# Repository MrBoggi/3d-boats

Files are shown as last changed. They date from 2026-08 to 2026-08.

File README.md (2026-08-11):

# 3dBoats

A collection of parametric OpenSCAD boat projects intended for 3D printing.

## Repository layout

```text
3dBoats/
├── projects/   # Individual printable boat projects
├── shared/     # Reusable OpenSCAD modules and component wrappers
└── scripts/    # Repository-wide build helpers (when added)
```

Each directory under `projects/` contains its own source files, build script,
and project-specific documentation.

## Projects

- [`projects/01-21ft-rib`](projects/01-21ft-rib/) — 1:10 scale, 660 mm RC RIB
  with a three-part V-hull, removable interior, and steerable outboard motor.

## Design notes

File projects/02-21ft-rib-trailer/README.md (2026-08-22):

# Båthenger for 21 ft RIB — designplan

Parametrisk boggihenger i skala 1:10, utviklet for båten i
[`../01-21ft-rib`](../01-21ft-rib/README.md). Hengeren skal kunne vises sammen
med båten, skrives ut på Bambu Lab A1 og bygges som en funksjonell RC-modell
med roterende hjul, vippbar boggi og justerbare skrogstøtter.

## Status

Detaljert digital review-versjon er implementert. Den inneholder komplett
sammenstilling, direkte skrogreferanse fra prosjekt 01 og 35 separate
eksportmål. En forstørret todelt V-front, rammeskjøter, tverrbjelkefester,
boggi-endestopp, M4-hjulaksler, synlige M4-muttere og separate 12 mm sekskantadaptere med avstandshylse,
justerbare støtter og en fremoverlent, avstivet vinsjstolpe med V-stopp på båtsiden er modellert. Modellen er kontrollert
med OpenSCAD, men ikke fysisk printet eller verifisert.

## Kjøpt RC-kobling

[AliExpress-produkt 1005005631960547](https://www.aliexpress.com/item/1005005631960547.html) er et AJRC justerbart `drop hitch receiver` for bilsiden på 1:10-crawlere som TRX-4 og SCX10. På hengeren trengs den matchende metallkloen, ikke en kopi av bilfestet.

CAD-en bruker den vanligste dokumenterte 1:10-standarden:

- 5,8–6,0 mm kule på trekkbilen;
- trailerklør for 6 mm kule;
- omtrent 35 mm lang metallklo;
- M3-gjenget sokkel i bakkant av kloen;
- 9 mm M3-stud ut fra hengeradapteren.

Et dokumentert eksempel er [Absima 2320126](https://rcmodelshopdirect.com/shop/accessories/rc-crawler-accessories/absima-1-10th-trailer-hitch-2320126/), som oppgir 35 mm lengde, M3-sokkel og 6 mm kule. Kompatible 6 mm kulefester finnes også fra [Integy](https://integy.shop/products/rock-crawlers-hop-up-parts-c33970). Produktet og AliExpress-variantene er `example`, ikke fysisk testet. Kontroller at valgt bilfeste leveres med 5,8–6 mm kule, og kjøp en trailerklør med M3-sokkel hvis den ikke følger med.

Hengeren har en separat printet frontadapter. Den overlapper senterbjelken 18 mm og festes med to vertikale M3-bolter. En fanget aksial M3-skrue gir 9 mm gjengestud til metallkloen. Adapteren kan dermed endres senere uten å printe V-draget på nytt.

## Visuelle referanser

Utformingen følger vanlige radius-toppskjermer for tandemakslede båthengere,
brede rektangulære LED-baklys og Y-/V-formede baugstopp på vinsjstolpen:

- [Tandemskjermer – BoatTrailerParts](https://www.boattrailerparts.com/Tandem-Axle-Boat-Trailer-Fenders_c_85.html)
- [Skrå vinsjstolpe med avstiving – BoatTrailerParts](https://www.boattrailerparts.com/Boat-Trailer-Winch-Post-Angled-3-inch-x-3-inch-x-24-inch-Tall-Galvanized_p_1960.html)
- [45° justerbar vinsjstolpe – etrailer](https://www.etrailer.com/search/Bow%2Bstop%2Bpost)
- [Plassering av baugstopp – etrailer](https://www.etrailer.com/faq-4-choices-buying-a-boat-trailer.aspx)
- [Rektangulære båthengerlys – EZ Loader](https://ezloadertrailers.com/products/ez-loader-updated-taillight-set-7-5-x-3-5-411-3002)

Referansene angir form og plassering; komponentene i CAD er egne skalerte
printdeler og er ikke fysisk testet.

## Grunnlag fra prosjekt 01

| Egenskap | Verdi |
|---|---:|
| Skala | 1:10 |
| Båtlengde | 660 mm |
| Maksimal båtbredde | 252 mm |
| Skrogtype | V-bunn, 26° referanse-deadrise, integrerte pongtonger |
| Båtens koordinater | X baug→hekk, Y babord→styrbord, Z kjøl→opp |
| Målskriver | Bambu Lab A1, 256 × 256 × 256 mm |

Hengermodellen skal importere eller gjengi skrogets kontaktprofil fra prosjekt
01. Parallelle, manuelt kopierte skrogmål skal unngås.

## Foreslått hovedkonsept

- Sveiset stålramme gjengitt som en modulær, printet kanal-/boksramme.
- A-ramme i front med kulekobling, langsgående 12 × 18 mm senterbjelke og fremoverlent vinsjtårn med doble skråstag på framsiden.
- V-baugstoppen står på båtsiden av vinsjtrommelen, slik at skroget stoppes før det kan nå trommel eller sveiv.
- To langsgående hovedvanger med tverrbjelker og separate skjøtestykker.
- Tandemakslet boggi på hver side. Hver boggi vipper rundt ett sentralt lagerpunkt,
  slik at begge hjul kan følge underlaget.
- Fire kjølruller langs senterlinjen tar hovedvekten.
- To par justerbare dobbeltrullestøtter støtter V-bunnen uten å belaste pongtongene.
- Motorens senterlinje holdes åpen bak X = 585 mm; forstørrede baklys og skilt sitter på bjelken foran.
- Én lang, buet tandemskjerm per side dekker begge hjul og festes med separate M3-braketter.
- En utskiftbar V-formet baugstopp i TPU sitter over vinsjtrommelen og tar imot V-baugen uten å bære skrogvekten.
- Baugstøtte og vinsjtrommel låser båten i lengderetningen. En egen akterstropp
  reserveres i modellen.

## Foreløpig dimensjoneringskonvolutt

| Parameter | Startverdi | Begrunnelse |
|---|---:|---|
| Total lengde | 800 mm | 660 mm båt, drag og klaring ved hekk |
| Ramme fra baugstøtte til akterende | 700 mm | Full understøttelse av skroget |
| Ytre rammebredde | 220 mm | Under båtens 252 mm maks. bredde |
| Sporvidde, hjulsenter | 290 mm | Klaring utenfor pongtongene |
| Maksimal totalbredde | 317 mm | Foreløpig hjul-/skjermkonvolutt |
| Hjuldiameter / reservert bredde | 65 / 27 mm | AliExpress-hjul; bredde må kontrollmåles |
| Hjulaksel | M4 × 55 mm | Ø4,3 mm klaringshull og fanget skruehode |
| Akselavstand i boggi | 78 mm | Klaring mellom 65 mm hjul |
| Bakkeklaring under ramme | 22 mm | Funksjonell modell på jevnt underlag |
| Klaring mellom skrog og hard støtte | 1.0 mm | Plass til myke støtteflater |
| Boggiens vinkelutslag | ±12° | Terrengbevegelse uten kontakt med ramme |

Valgt eksempel er [AliExpress-produkt 1005009693636383](https://www.aliexpress.com/item/1005009693636383.html), oppgitt som ARRMA
ARA550116-kompatibelt hjul med diameter 65 mm og 12 mm sekskantfeste. CAD-en
reserverer 27 mm hjulbredde inntil et fysisk hjul kan måles. Hvert hjul monteres med en separat printet sekskantadapter med integrert
avstandshylse, M4 × 55 mm skrue, to skiver og M4 låsemutter. Skrue, skiver
og mutter vises nå også i normal `assembly`, mens klaringsvolumene fortsatt
styres av `show_hardware`. Adapteren er 11,5 mm over flatene for 0,25 mm klaring per side.
Produktet er foreløpig et eksempel, ikke fysisk testet. ARRMA oppgir 12 mm
sekskantfeste for ARA550116, og det tilhørende GROM-akselsettet ARA311231
bruker M4-hjulmuttere: [hjuldata](https://www.arrma-rc.com/en/product/arrma-dboots-fortress-tire-set-glued-red-2-pairs/ARA550116.html) og
[akseldata](https://www.arrma-rc.com/de/product/arrma-metal-axle-and-wheel-hex-set-b-4-grom/ARA311231.html).

Alle startverdier skal ligge i `scad/config.scad` og kunne justeres etter første
digital prøvepass. Totalbredden er større enn byggeplaten, så aksler,
boggiarmer og hjul må være separate deler.

## Designfaser

### 1. Lås båtens plassering og kontaktpunkter

Plasser båten med samme X/Y/Z-retning som i prosjekt 01. Definer et eget
`boat_reference`-oppsett med:

- kjølens høyde langs X;
- V-bunnens høyde ved valgte støttebredder;
- maksimal pongtongkonvolutt;
- motorens og akterspeilets frie område;
- båtens tyngdepunkt som en justerbar antakelse frem til det måles fysisk.

Første mål er minst 5 mm fri avstand mellom hard hengerramme og skrog/pongtong
ved nominell plassering.

### 2. Lag en enkel layoutmodell

Modeller først bare klaringsvolumer for båt, hjul, aksler, kobling og
vinsjtårn. Kontroller ovenfra og fra siden at:

- båten er sentrert og ikke treffer skjermer eller vinsjtårn;
- akterspeil og påhengsmotor har fri passasje gjennom den åpne akterenden;
- estimert tyngdepunkt ligger litt foran boggisenteret;
- kulekoblingen får tilstrekkelig sving- og høydeklaring.

### 3. Dimensjoner ramme og utskriftsdeling

De parallelle hovedvangene starter ved X = 276 mm, direkte mot bakkanten av tverrbjelken ved X = 270 mm, og deles ved X = 440 mm.
Fronten er en stor V fra koblingen ved X = -108 mm til vangene ved X = 270 mm.
V-en deles ved X = 60 mm med 10 mm overlapp og gjennomgående M3-skruer. Tverrbjelkene skal være separate slik at samlet bredde ikke bestemmer
utskriftsretningen. Legg mest materiale rundt boggifeste, vinsjtårn og skjøter.

### 4. Utvikle boggien som egen mekanisme

Hver side får én vippende boggiarm med to separate hjulaksler. Reserver først
hardware-konvolutter for M4 × 55 mm hjulskruer, skiver, låsemuttere og
separate 12 mm sekskantadaptere. Boggiens senterbolt skal være tilgjengelig uten å demontere rammen.
Mekaniske endestopp begrenser vinkelutslaget og hindrer at dekk treffer rammen.

### 5. Tilpass kjølruller og sidestøtter

Plasser kjølruller ved omtrent X = 110, 270, 430 og 591,3 mm i båtens koordinater,
og finjuster dem mot den faktiske kjølkurven. Sidestøttene plasseres parvis nær
de to midtre/akterste sonene, med vinkel bestemt av skrogets lokale V-flate.
Støttehodene skal være utskiftbare og ha flater for TPU-, filt- eller
gummibelegg. Pongtongene skal ikke være lastbærende.

### 6. Legg til opptrekk og sikring

Vinsjtårnet heller omtrent 29° fremover fra vertikalen. Den brede fotplaten er erstattet av en 12 × 18 mm senterbjelke fra V-spissen til tverrbjelken ved X = 34 mm. Stolpefoten står direkte på dette krysningspunktet med gjennomgående M3-feste, mens to diagonaler lander på senterbjelken foran. Baugstoppen er en separat, kompakt TPU-V mellom to faste gaffelører på båtsiden av trommelen. En gjennomgående M3-pivot med 0,4 mm sideklaring, skiver og låsemutter lar hele V-klossen selvjustere opptil ±15° i lengderetningen,
og vinsjen får gjennomgående aksel og håndsveiv. Modellen reserverer føring for
line, sikkerhetskjetting og stroppepunkter ved akterenden. Dette modelleres etter
at båtens hvilestilling er låst.

### 7. Verifiser og iterer

Lag først små prøveutskrifter av rammeskjøt, boggilager, hjuladapter og én
skrogstøtte. Deretter:

1. Render alle deler enkeltvis og som komplett henger.
2. Render en debug-sammenstilling med båt og alle hardware-konvolutter.
3. Kontroller manifold geometri og byggevolum for hver eksport.
4. Print én boggi og test vipping, hjulfrigang og skrueadkomst.
5. Print en kort rammeseksjon med støtte og fysisk prøv mot skroget.
6. Monter full ramme, juster støttehøyder og mål faktisk kuletrykk.
7. Lås parametere først etter rulle-, sving- og lastetest med den ferdige båten.

## Filstruktur

```text
02-21ft-rib-trailer/
├── README.md
├── build.sh
├── scad/
│   ├── config.scad
│   ├── hardware.scad
│   ├── boat_reference.scad
│   ├── frame.scad
│   ├── bogie.scad
│   ├── fenders.scad
│   ├── coupler.scad
│   ├── supports.scad
│   ├── winch.scad
│   └── assembly.scad
├── stl/
├── 3mf/
└── png/
```

`assembly.scad` har en `selected_part`-velger for hver printdel. Variablene
`show_boat`, `show_outboard`, `show_road` og `show_hardware` styrer henholdsvis
skrogreferansen, den komplette motorreferansen, veireferansen ved Z = 0 og
hardware-konvoluttene. `show_keel_contact_debug=true` legger fire
ugjennomsiktige turkise skrogsnitt over kjølrullene, slik at anlegget kan
vurderes uten transparent-overlapping.
Motoren gjenbrukes fra båtprosjektets originalmodell med original kort stamme
og motorfeste. XL-avstandsstykket er ikke med i trailervisningen. Motoren vises
uten tilt, slik at akter- og propellklaringen kan vurderes mot veien.

## Bygg og forhåndsvisning

Åpne hele sammenstillingen med båten:

```sh
openscad scad/assembly.scad
```

Eksporter én del, for eksempel boggiarmen:

```sh
openscad -o bogie_arm.stl \
  -D 'selected_part="bogie_arm"' \
  -D 'show_boat=false' \
  scad/assembly.scad
```

Etter visuell godkjenning eksporteres hele settet og tre PNG-visninger med:

```sh
./build.sh --approved
```

## Implementerte printmål

- Ett 164 mm midtsegment og ett 145 mm aktersegment per hovedvange; vangene slutter ved X = 585 mm.
- To utvendige skjøtelasker, én på yttersiden av hver vange ved X = 440 mm. Innvendige lasker er fjernet fordi de kolliderte med midtbjelkens festeområde.
- Én fullbredde frontbjelke ved X = 270 mm, én egen forkortet midtbjelke ved X = 430 mm og én tilpasset lysbjelke ved X = 591,3 mm. Den tidligere tverrbjelken i vangskjøten ved X = 440 mm er fjernet, slik at skjøteboltene ikke ligger i en delesøm.
- Midtbjelken har 0,3 mm sideklaring til vangene; lysbjelken har 0,3 mm endeklaring bak vangene. Hver skjøt bruker egne 3 mm over-/underplater på begge sider, totalt fire plater per bjelke.
- V-bakdelen stopper plant ved forkanten av tverrbjelken ved X = 270 mm, og hovedvangene starter ved bakkanten. Fire identiske 3 mm skjøteplater, én over og én under på hver side, forbinder V-arm, tverrbjelke og hovedvange med tre M3-bolter per side.
- Todelt, forstørret V-front med en reell halv-i-halv-skjøt, 0,3 mm vertikal printklaring og to M3-bolter per arm, integrerte broer og langsgående senterbjelke frem til vinsjtverrbjelken.
- Separat frontadapter med 18 mm halv-i-halv-tunge, 0,3 mm vertikal klaring, to M3-rammebolter og aksial M3-stud for kjøpt 6 mm trailerklør.
- To boggiarmer og to åpne clevisfester med 4 mm inner-/ytterører, 1,2 mm lagergap, 0,8 mm skiver og fanget M3-mutter. Hvert feste har toppflens og to vertikale M3-bolter gjennom hovedvangen; endestoppene gir verifisert ±12° utslag.
- Fire separate PETG/ASA-sekskantadaptere for kjøpehjul med 12 mm feste og integrert Ø10 mm avstandshylse.
- Alle bærende rammebjelker har 12 × 18 mm profil, slik at V-front, hovedvanger og tverrbjelker møtes med plane over- og undersider uten påbygde kiler.
- Fire kjølruller og åtte separate, speilbare sidebraketter som står på oversiden av V-broen eller tverrbjelken og festes i samsvarende M3-hull. Rullene har en konkav 26° V-profil, Ø7 mm i senter og Ø23 mm ved endene. Holderne består av to speilbare, separate sidebraketter per rull, er åpne under rullens rotasjonsbane og har sideføtter, 1 mm aksial endeklaring og minst 0,4 mm radial klaring over bjelken. Båtens referansehøyde er løftet 6 mm for å gi plass til den reelle V-rullekonvolutten. Akselhøydene er avledet fra skrogets målte kjølhøyde ved hver stasjon og gir minst 0,3 mm digital klaring til den analytiske V-bunnen.
- Fire støttehylser med bolteflens mot tverrbjelkene, fire justerbare poster, fire bolteforbundne rulleåk og åtte separate sideruller. Hver siderulle sitter i en separat wobble-holder med M3-sekundærpivot rundt X-aksen, ±10° mekanisk utslag og fysiske endestopp. Hovedåket har Y-pivot mot støtteposten og skrogavledet lengdevipp på ca. -3,0° foran og -0,04° bak. Siderullene har en svakt konveks TPU-profil, Ø16 mm i midten og Ø13 mm ved endene, for å redusere kantkontakt.
- Fremoverlent vinsjstolpe uten bred fotplate; stolpefoten treffer vinsjtverrbjelken direkte, og doble frontstag treffer senterbjelken med hvert sitt M3-feste. Trommel, sveiv og boltet V-baugstopp på båtsiden er separate deler.
- To forstørrede lyktehus ved Y = ±106 mm, to røde linser med to demonterbare M2-fester hver og én sideforskjøvet skiltplate.
- To buede tandemskjermer med lukket, ringformet innerkant og åpne hjulflater. Midtbrakettene er flyttet opp på clevisenes toppbro og boltes vertikalt der, slik at armkanal og hovedvange holdes fri.
- V-formet, boltet og kompakt baugstopp med 18 mm spenn som separat TPU-del.
- Ingen tverrbjelke ved X = 652 mm; motorens bakre klaringssone er åpen.

Støttehjul, innføringsruller og stroppeører er ikke med i denne
review-versjonen.

## Verifiserte mekaniske grensesnitt

Etter første fysiske prøveutskrift ble den tidligere geometriske overlappingen mellom `drawbar_front` og `drawbar_rear` fjernet. Delene skal ikke skrus oppå hverandre som to massive bjelker. De har nå komplementære halv-i-halv-anlegg med 0,3 mm nominell vertikal klaring; de fire M3-hullene klemmer halvdelene sammen. Koblingsadapterens tunge bruker samme prinsipp mot senterbjelken.

Midtbjelken ender 0,3 mm innenfor hovedvangene og lysbjelken starter 0,3 mm bak vangeendene. Begge forbindes med separate 3 mm plater over og under, to per side. Dermed finnes det ikke lenger massive bjelkevolumer som opptar samme plass. Sidestøtten har et rundt hovedpivotnav i en gaffel, og hver av de to siderullene har sin egen sekundærpivot med fri knastklaring.

Kjør `scripts/check_joint_interfaces.sh` etter geometriendringer. Kontrollen rendrer alle 35 printfiler og krever `Simple: yes`, og den krever tomt kollisjonsvolum i åtte kritiske grensesnitt. Dette er digital passkontroll; den nye V-skjøten og de nye tverrbjelkeplatene må fortsatt bekreftes med små fysiske prøveutskrifter før hele rammen printes.

## Printorientering

| Del | Anbefalt orientering |
|---|---|
| Koblingsadapter | Største flate ned; test M3-stud før full montering |
| V-frontseksjoner | Største flate mot byggeplaten |
| Hovedvanger og tverrbjelker | Største flate mot byggeplaten |
| Lyktehus, linser og skiltplate | Største flate ned |
| Skjøtelask | Flatt |
| V–vange-skjøteplate | Flatt; print fire identiske |
| Boggiarm | Stor sideflate ned |
| Boggifeste | Rammeanlegget ned |
| Hjuladapter og kjølrulle | Én rund side ned; vurder støtte i navhullet |
| Tandemskjerm | Legg på én langside; støtte under buen kan bli nødvendig |
| Skjermbrakett | Flatt |
| V-baugstopp | Stor sideflate ned, TPU |
| Baugøye (prototype) | Stor monteringsflate ned; metallutførelse eller forsterket PETG/ASA må vurderes |
| Støttehylse og post | Største flate/side ned |
| Rulleåk | Største flate ned |
| Wobble-holder | Største flate ned; print åtte identiske |
| Siderulle | Én rund side ned |
| Vinsjtårn | Fot/anleggsflate ned; lokal støtte kan bli nødvendig |

Alle 35 eksportdeler er eksportert til STL og kontrollmålt fra den faktiske
triangelgeometrien. Samtlige kompilerer som `Simple: yes` og ligger innenfor
256 × 256 × 256 mm. Største todimensjonale fotavtrykk er `drawbar_rear`
på ca. 214 × 217 mm; tverrbjelkene er 220 mm lange. Alle delene er også
slicet digitalt på korrekt A1-plate som beskrevet under.

## Slicer-verifikasjon

Alle 35 STL-er er slicet med Bambu Studio 2.7.1.62 Flatpak mot Bambu Lab A1,
0,4 mm dyse og 0,20 mm Standard. De strukturelle delene ble kontrollert med
Generic PETG; `bow_stop` ble i tillegg kontrollert med Bambu TPU 95A. Alle
deler ble beholdt i dokumentert eksportorientering, med kun platearrangering
og eventuell rotasjon rundt Z-aksen.

Bambu Studio-CLI-en mistet A1-profilens arvede platepolygon og falt tilbake til
200 × 200 mm. `drawbar_rear` og de to 220 mm tverrbjelkene ble derfor også
kontrollert via 3MF med A1-profilens faktiske 256 × 256 mm polygon; alle tre
slicet uten advarsel. Seks deler trenger normal automatisk støtte:

- `coupler_mount_adapter`;
- `side_double_roller_cradle`;
- `side_roller_wobble_holder`;
- `tandem_fender`;
- `wheel_hex_adapter`;
- `winch_tower_body`.

Disse seks ble slicet på nytt med `normal(auto)` støtte og ga generert
støttemateriale uten gjenværende advarsler. Etter clevis-redesignet trenger
også `bogie_mount` automatisk støtte. Den separate TPU-filen for `bow_stop`
bruker også automatisk støtte for å unngå flytende regioner. Automatisk brim var aktivert, men
profilen valgte 0 mm brim for kontrollkjøringene. Standardprofilens to vegger
og 20 % infill dokumenterer bare slicbarhet; endelige styrkeinnstillinger må
fastsettes før fysisk prototype.

Etter clevis-redesignet er `bogie_mount`, `bogie_arm`, `fender_mount_bracket`
og `frame_rail_rear` eksportert på nytt som `Simple: yes` og slicet på nytt
med samme A1/PETG-kontrollprofil; alle fire besto. Den forkortede
`wheel_hex_adapter` ble også eksportert og slicet på nytt uten feil. Komplett
trailer uten båt ble til slutt CGAL-rendret som `Simple: yes`.

## Permanente 3MF-filer

Mappen `3mf/` inneholder én ferdig Bambu Studio-prosjektfil for hver av de 35
unike eksportdelene. Hver fil inneholder én kopi av delen og kan åpnes direkte
i Bambu Studio. Kopiantall velges ved utskrift etter delelisten/monteringen.

Prototypeprofilene er:

- Bambu Lab A1 med 0,4 mm dyse og 0,20 mm laghøyde;
- Generic PETG, 4 vegger, 5 topp- og bunnlag, 35 % gyroid for alle harde deler;
- Bambu TPU 95A, 4 vegger, 5 topp- og bunnlag, 25 % gyroid for `bow_stop`;
- 5 mm ytre brim på høye/smale poster og braketter;
- `normal(auto)` støtte på `coupler_mount_adapter`, `bogie_mount`,
  `side_double_roller_cradle`, `side_roller_wobble_holder`, `tandem_fender`,
  `wheel_hex_adapter`, `winch_tower_body` og TPU-delen `bow_stop`.

Alle 35 pakkede filer er kontrollslicet på A1-plate 256 × 256 mm uten
gjenværende advarsler. Innstillingene er et sterkt utgangspunkt for
prøveutskrift, men er ikke fysisk lasttestet. Kontroller valgt filament og
byggeplate i Bambu Studio før utskrift.

Undermappen `3mf/plates/` inneholder i tillegg ferdig arrangerte prosjekter
med full stykkmengde for én henger: fire PETG-prosjektfiler med totalt 84 printdeler, fordelt over fire fysiske platefaner, og én separat TPU-plate med baugstoppen. `3mf/plates/README.md` viser nøyaktig
innhold på hver plate. Prosjektene genereres reproducerbart med
`scripts/build_plate_3mf.py`; generatoren kontrollerer arkivintegritet, antall
instanser og alle interne objektreferanser.

## Obligatorisk skjøtetest før restutskrift

Ikke print `3mf/remaining_after_trial/` før `3mf/fit_tests/fit_test_plate_01.3mf` er printet og alle seks grensesnitt er fysisk godkjent. Testplaten inneholder 18 objekter på én A1-fane og bruker fullskala utsnitt fra den samme produksjonsgeometrien. Monteringsrekkefølge og godkjenningskriterier står i `3mf/fit_tests/README.md`. Testpakken genereres med `python3 scripts/build_fit_test_plate.py`.

Under utviklingen av testkupongen ble det oppdaget at V-armenes union fylte de to M3-hullene i koblingsområdet. Produksjonsfronten er korrigert slik at hullene nå skjæres gjennom den komplette unionen. Dette bekrefter hvorfor fysisk kupongtest er obligatorisk før flere store deler printes.

## Restutskrift etter fysisk prøveprint

Et eget restsett ligger i `3mf/remaining_after_trial/`. Det bygger på at begge fysiske faner i de gamle PETG-prosjektene 01 og 02 er printet, mens bare fane 1 i gamle prosjekt 03 er printet. `winch_tower_body` er eksplisitt tatt med fordi delen manglet i den fysiske utskriften, selv om den gamle prosjektmetadataen plasserte den på fane 1.

Restsettet inneholder 54 PETG-deler og én TPU-baugstopp fordelt på seks fysiske faner. Det inkluderer både tidligere uprintede deler og alle deler som må printes på nytt etter halv-i-halv-skjøten, de nye tverrbjelkefestene og redesignet sidestøtte. Alle seks faner er kontrollslicet med returkode 0 og uten advarsler. Regenerer settet med `python3 scripts/build_remaining_after_trial.py`.

## Visuell service-review

Service-reviewen er utført med seks fokuserte visninger i `png/review_service_*.png` og gule hardware-akser. Følgende er visuelt tilgjengelig uten modellendring:

- alle fire utvendige hjulmutre;
- høydejustering, hovedpivot og rulleaksler på sidestøttene;
- kjølrulleaksler og deres vertikale brakettfester;
- vinsjtrommelaksel, baugstopperpivot og de vertikale tårn-/stagfestene;
- baklyshus, avtakbare linser og skiltplate fra aktersiden.

Skjermens innerfeste og boggipivoten ligger mellom hjulene og krever minst at
ett hjul tas av for komfortabel verktøytilgang. Hjulmutteren er direkte
tilgjengelig, så denne servicerekkefølgen er mulig.

Den opprinnelige massive boggiblokken er erstattet av en reell clevis med fri
armkanal, to 4 mm ører, 1,2 mm lagergap, 0,8 mm skiver og fanget M3-mutter i
innerøret. En M3 × 18 mm bolt føres inn fra utsiden. Eksakte interseksjoner er
tomme i nøytralstilling og ved ±11°, mens begge mekaniske stoppene får kontakt
ved ±12°. Clevis, pivothardware og fullt hjulsveip er tomme mot skjerm og
skjermbrakett. Skjermbraketten sitter nå separat på clevisens toppbro.

## Monteringsrekkefølge for prototype

1. Print og prøv V–vange-skjøteplaten, skjøtelasken, én sekskantadapter og én boggiarm.
2. Monter V-bakdelen mot forkanten av fremre tverrbjelke, hovedvangene mot bakkanten, og lås knutepunktet med skjøteplater over og under før resten av rammeskjøtene trekkes til.
3. Monter boggifester, boggiarmer og fire hjul; kontroller fritt utslag.
4. Monter kjølruller og sidestøtter uten å stramme endelig.
5. Sett båten på hengeren, juster støttehøydene og sjekk minst 5 mm hardklaring.
6. Plasser vinsjtårn og baugstopp etter båtens faktiske hvilestilling.
7. Mål kuletrykk og flytt boggi eller båt før parameterne låses.

## Material- og hardware-retning

PETG eller ASA er utgangspunkt for ramme og mekaniske deler; TPU er aktuelt for
dekk og myke ruller. Endelig hardware velges etter prøvegeometri. Hjulene bruker M4-festemidler; øvrige boggipivoter, rammeskjøter og justerbare
støtter bruker foreløpig M3. Ingen
gjenger modelleres direkte; bruk klaringshull, mutterlommer eller varmeinnsatser.

| Komponent | Status | Reservert CAD-konvolutt |
|---|---|---:|
| 6 mm RC-kule på bil | example | Matchende trailerklør kreves |
| M3-gjenget trailerklør | required | Ca. 35 mm; for 5,8–6,0 mm kule |
| Printet koblingsadapter | required | 32 × 24 × 14 mm + 18 mm tunge; 2 × M3 rammefeste |
| M4 × 55 mm hjulskrue | required | Ø4,3 mm klaringshull; fanget 7 mm skruehode |
| M4 skiver og låsemutter | required | 2 skiver per hjul; mutter 7 mm AF × 4 mm |
| Printet hjuladapter | required | 11,5 mm AF hex × 5,5 mm; Ø18 × 2 mm flens; Ø10 × 6,5 mm hylse |
| [AliExpress 1005009693636383](https://www.aliexpress.com/item/1005009693636383.html) | example | Ø65 × reservert 27 mm; 12 mm hex |
| M3 × 18 mm boggipivot | required | Ø3,4 mm klaringshull; 2 × Ø7/0,8 mm skiver; fanget 5,5 mm AF låsemutter |
| M3 rammeskjøt | required | Ø3,4 mm klaringshull |
| M3 boggi-, skjerm-, rulle-, støtte- og vinsjfeste | required | Samsvarende Ø3,4 mm gjennomgående hull |
| M2 linsefeste | required | Ø2,2 mm linseklaring og Ø1,6 mm pilot i lyktehus |
| M3 mutter | example | 6,2 × 5,5 × 2,6 mm |
| Hjulbredde | example | 27 mm CAD-reserve; må kontrollmåles fysisk |
| Mykt rulle-/støttemateriale | required | TPU, filt eller gummi, ikke valgt |
| Baklys/LED | example | Hus 8 × 38 × 20 mm; linse 3 × 34 × 16 mm |
| Tandemskjerm | required | 35 mm bred; lukket ringkant med åpne hjulflater; 11 mm radiell klaring for fullt ±12° boggiutslag, 2 mm aksial klaring; 2,4 mm gods |
| Skjermbrakett | required | To midtbraketter på clevisens toppbro; vertikal M3 i clevis og horisontal M3 i skjerm |
| V-baugstopp | required | Kompakt 20 × 18 mm TPU-V med 4 mm armer og Ø9 × 7 mm pivotboss; mellom to 3 mm gaffelører, 0,4 mm sideklaring og ±15° fritt utslag |
| Baugøye (båtprosjekt) | prototype | Ø10/5 × 3 mm ring på 26° V-sadel; 2 × M2 gjennom skroget og separat innvendig V-backingplate |
| 1:10 vinsjstropp | example | 2,5 mm nominell flat nylonstropp; reservert konvolutt 3,5 × 1 mm med krok opptil 8 × 5 × 3 mm; festet til vinsjtrommelen og kroket gjennom Ø5 mm baugøye |
| Skiltplate | example | 3 × 42 × 16 mm |

## Godkjenningskriterier

- Båten hviler på kjøl og V-bunn uten hard kontakt mot pongtongene.
- Minst 5 mm fri avstand til ramme og minst 2 mm til bevegelige/hjulnære deler.
- Alle fire hjul roterer fritt og begge boggier kan vippe til mekaniske endestopp.
- Påhengsmotor, støtter, skjermer og vinsjtårn kolliderer ikke i bruk.
- Hver printdel passer innenfor 256 × 256 × 256 mm i dokumentert orientering.
- Alle servicebolter og muttere er tilgjengelige etter montering.
- Sammenstillingen kan demonteres uten å bryte limte hovedkomponenter.
- Fysisk lasttest og faktisk kuletrykk er dokumentert før designet merkes ferdig.

## Digital verifikasjon

- [x] Komplett trailer uten båt rendret med CGAL: `Simple: yes`.
- [x] Alle 35 separate eksportmål rendret: `Simple: yes`.
- [x] Faktiske STL-avgrensninger for alle 35 eksportdeler er målt; største
  fotavtrykk er 214 × 217 mm og alle tre akser er under 256 mm.
- [x] Isometrisk PNG oppdatert med den faktiske RIB-referansen.
- [x] Hardware-debug dekker ramme, boggifestebolter, hjul, rullefester og aksler, støtteflenser og pivoter, skjermfester, vinsjstag, baugstopp, lys, linser og skilt.
- [x] Alle åtte sideruller i arbeidsstilling er testet mot detaljert skrogmesh med eksakt CGAL-interseksjon: tomt resultat.
- [x] Boggiens endestopp og skjermradius er beregnet for ±12° utslag med 2 mm ekstra løpeklaring; egen kontrollvisning viser nøytralstilling og begge endestopp.
- [x] Sveipet hjulvolum gjennom hele boggiutslaget er CGAL-testet mot skjerm og brakett: tom interseksjon.
- [x] Hardt vinsjtårn er CGAL-testet mot skroget: tom interseksjon.
- [x] Baugstopperens lokale V-flate er CGAL-testet mot det eksakte 2,8 mm baugskallet gjennom hele -15° til +15° vandringen. Nominell arbeidsvinkel er +10°, med verifisert kontakt og tom gaffelinterseksjon.
- [x] Separat baugøye i båtprosjektet og flat vinsjstropp er modellert; stroppbanen er CGAL-testet mot V-stopper og gaffel med tom interseksjon.
- [x] Maksimal kjøpekonvolutt på 3,5 × 1 mm stropp og 8 × 5 × 3 mm krok er CGAL-testet mot frontmekanismen: tom interseksjon.
- [x] Leverandørmotorens lukkede maksimumskonvolutt på 100 × 70 × 166 mm er CGAL-testet mot vei og trailerens ramme/lysbjelke: begge interseksjoner er tomme.
- [ ] Baugøyets V-sadel, to M2-skroggjennomføringer og innvendige backingplate er modellert; materialvalg, tetting og fysisk lasttest gjenstår.
- [ ] Visuell eier-review av proporsjoner og skrogkontakt.
- [x] Visuell service-review utført med fokuserte bilder; hjul, støtter, vinsj og baklys har identifisert servicetilgang.
- [x] Boggifestet redesignet som clevis med komplett M3 × 18 mm pivot; arm er fri til ±11°, stopper ved ±12°, og clevis/pivot/hjulsveip er tomme mot skjermsystemet.
- [x] Alle 35 permanente 3MF-filer slicet med Bambu Studio 2.7.1.62 for A1/0,4 mm uten advarsler; sju PETG-deler og TPU-baugstoppen bruker normal automatisk støtte.
- [ ] Fysiske testutskrifter av skjøt, hjuladapter, boggi og justerbar støtte.
- [ ] Last-, klarings- og kuletrykktest med ferdig båt.

## Åpne valg etter review

- Fysisk kontrollmål av kjøpehjulets bredde og dybden på 12 mm hex-lommen.
- Type modellkobling og diameter/høyde på trekkpunktet.
- Om vinsjen skal være funksjonell eller primært skalamessig.
- Om ekstra sidemarkeringslys skal inngå i første produksjonsversjon.
- Faktisk vekt og tyngdepunkt for ferdig båt med batteri og motor.

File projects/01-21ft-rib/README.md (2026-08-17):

# 21 ft RIB — 1:10 RC model

Parametric 660 × 252 mm RIB for a Bambu Lab A1. The approved design uses a three-section V-hull, integrated pontoons, a flat removable cockpit floor, removable interior modules, and a steerable 1:10 outboard.

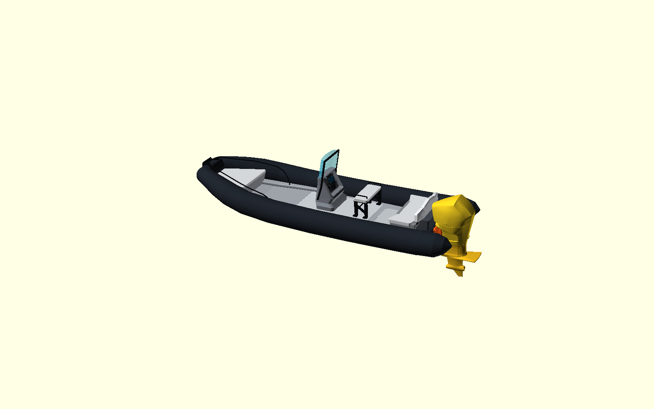
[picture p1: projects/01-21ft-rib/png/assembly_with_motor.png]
Complete 21 ft RIB assembly


## Status

The hull form, floor, helm console, helm bench, aft bench, bow seat and rails, transom interface, and XL outboard adapter are visually approved and design-locked. OpenSCAD compilation is checked before release. Production STL export, slicer review, physical fit, flotation, sealing, and water testing remain required.

## Main dimensions

| Item | Value |
|---|---:|
| Scale | 1:10 |
| Full-size class | 21 ft / approximately 6.6 m RIB |
| Model length | 660 mm |
| Maximum beam | 252 mm |
| Hull sections | 220 / 210 / 230 mm |
| Hull wall | 2.8 mm |
| Nominal pontoon diameter | 54 mm |
| Target printer | Bambu Lab A1, 256 × 256 × 256 mm |

The beam leaves only 4 mm total build-plate margin. Verify orientation and disable any brim that exceeds the plate before slicing.

## Selected hardware

| Component | Design reference | Product size | Reserved CAD envelope |
|---|---|---:|---:|
| Outboard | [NoMatter RC Outboard Motor 1/10](https://www.printables.com/model/1191848-rc-outboard-motor-110), Mount 0 | Vendor STL assembly | Vendor geometry |
| Motor | Water-cooled 2948 brushless motor required by vendor design | Confirm before purchase | Vendor cavity |
| Cooling jacket | [Surpass Hobby 29S / C30507](https://integy.shop/products/rc-boats-parts-c30507) | 29 mm motor class | Vendor cavity |
| ESC | [Hobbywing SeaKing 60A V3.1](https://www.hobbywing.com/en/products/seaking-v3-series75.html) | 60.5 × 38.5 × 25.6 mm | 80 × 50 × 35 mm |
| Steering servo | [Savöx SW-0250MG+](https://www.teamsavox.com/product/sw-0250mgp/) | 29.5 × 14 × 32.5 mm body, 40 mm flange | 42 × 22 × 38 mm |
| Battery | [Gens ace G-Tech 3S 2200 mAh 25C](https://www.genstattu.com/gens-ace-2200mah-3s-25c-11-1v-g-tech-lipo-battery-pack-with-deans-plug/) | 106 × 34 × 22 mm, 166 g | 150 × 50 × 35 mm |
| Console display | [AliExpress OLED module 1005012699312062](https://www.aliexpress.com/item/1005012699312062.html) | PCB 27.8 × 27.3 mm; active area 21.74 × 11.2 mm | 22.5 × 12 mm window |
| Receiver | Minimum two channels; not selected | — | 55 × 35 × 25 mm |
| Optional UBEC | 5–6 V, at least 5 A | — | 45 × 25 × 15 mm |

The console display retainer uses M1.6 thread-forming screws. The helm bench, aft service cover, and servo mounting are prepared for heat-set inserts; [M2 × 3 mm inserts](https://cnckitchenus.store/products/heat-set-insert-m2-x-3-100-pieces) are the current reference. Confirm every purchased component with calipers before committing to final prints.

## Outboard and XL adapter

The unmodified vendor files belong in `vendor/printables-1191848/` and are intentionally ignored by Git. Attribution and reusable import logic live in `shared/components/outboards/`.

The locked Mount 0 interface uses four holes measured from the vendor STL: 32.69 × 22.31 mm spacing. The project adapter has 3.6 mm M3 clearances, a 16 mm centre clearance, and a reinforced transom interface.

The vendor lower unit is too short for the scaled XL transom. The separate printable `outboard_xl_adapter` adds 28.4085 mm without modifying vendor geometry. It follows the measured upper and lower mating contours, carries four 3.4 mm bolt passages with continuous bosses, and reserves a 4 mm passage for the longer 3 mm drive shaft. Seal both faces with a thin marine sealant gasket and determine final bolt length during physical trial assembly.

## Printable parts

`build.sh` exports only current production parts:

- Hull: bow, mid, and stern sections with alignment keys and optional M3 clamping holes.
- Floor: fixed sole, battery hatch, and aft service hatch.
- Console: shell, OLED retainer, and separate windshield hoop.
- Helm bench: cushion, port/starboard frames, cross braces, and side rails.
- Aft bench: servo cover, cushion, backrest, and seat support.
- Bow: locker base, cushion, port/starboard rails, and anchor roller.
- Propulsion: XL leg adapter. The vendor outboard remains an external dependency.
- Accessory: removable ladder.

## Source layout

```text
01-21ft-rib/
├── scad/   # Parametric OpenSCAD source
├── stl/    # 26 ready-to-share printable parts
└── png/    # Rendered assembly views
```

- `scad/assembly.scad`: production assembly and export selector.
- `scad/assembly_with_motor.scad`: complete visual assembly including vendor outboard.
- `scad/config.scad`: dimensions, component envelopes, tolerances, and locked datums.
- `scad/hull.scad` and `scad/hull_geometry.scad`: final hull and printable joints.
- Remaining part files correspond directly to current production assemblies.

Approved distribution files are committed in `stl/` and `png/`. Temporary development previews stay in ignored `preview/` folders.

## Build

Open and inspect the complete model first:

```sh
openscad scad/assembly_with_motor.scad
```

Export all approved project-owned parts:

```sh
./build.sh --approved
```

Individual parts can be exported through `scad/assembly.scad`, for example:

```sh
openscad -o outboard_xl_adapter.stl \
  -D "selected_part=\"outboard_xl_adapter\"" \
  scad/assembly.scad
```

## Print orientation

| Part group | Recommended orientation |
|---|---|
| Hull bow, mid, stern | Keel down; verify the 252 mm beam and plate margins |
| Bow eye | V-saddle against keel; print the internal backing plate separately |
| Fixed floor and hatch lids | Flat underside on the build plate |
| Console and bow locker base | Mounting base down |
| Seat cushions and backrests | Largest flat rear or underside face down |
| Bench frames, rails, windshield hoop, ladder | Largest flat side in the build plane; add local supports only where needed |
| XL outboard adapter | One machined mating flange down; verify bolt passages after slicing |

## Recommended print and assembly sequence

1. Print small interface samples for hull joints, heat-set inserts, servo, OLED, Mount 0, and XL adapter.
2. Dry-fit the vendor outboard, shaft, cooling hose, steering linkage, and electronics.
3. Print the three hull sections in PETG, ASA, or another water-resistant material. Use at least four perimeters and verify the 252 mm bed fit in Bambu Studio.
4. Bond hull joints with marine epoxy. Alignment keys position the sections; the M3 holes may clamp the joint while curing and provide mechanical redundancy.
5. Seal internal seams, insert pockets, and fastener penetrations. Leak-test the empty hull before installing electronics.
6. Install the flat floor and removable hatches, then console, benches, rails, servo, electronics, and outboard.
7. Check steering travel and hose/cable clearance through the full motor arc.
8. Perform bathtub flotation and trim tests before low-power water trials.

## Verification checklist

- [x] Approved geometry represented in the production assembly.
- [x] Hull split fits the nominal Bambu Lab A1 build volume.
- [x] Production export list excludes the abandoned internal drivetrain.
- [x] Bow eye is project-owned, separately exportable, and shown on the bow assembly.
- [x] Bow section contains two matching Ø2.2 mm holes at X = 38.5 and 45.5 mm; the eye and internal backing plate compile separately as manifold parts.
- [x] XL adapter has passed isolated CGAL manifold rendering (`Simple: yes`).
- [x] Full STL batch exported after the source-layout cleanup.
- [ ] Every STL sliced and checked in Bambu Studio.
- [ ] Purchased components measured and physically test-fitted.
- [ ] Hull sealed and leak-tested.
- [ ] Static flotation, trim, steering, and powered water tests completed.

## Licensing

Project-authored files follow the repository license when one is added. Vendor outboard files are not redistributed; follow the license and attribution terms on the linked Printables page.

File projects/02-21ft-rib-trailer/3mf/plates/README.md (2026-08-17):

# Ferdig arrangerte printplater

A1, 256 × 256 mm. Antallene dekker én komplett henger.
Prosjektfilene inneholder totalt 8 fysiske platefaner.

## trailer_petg_plate_01.3mf

Fysiske platefaner: 2

- `crossmember` × 1
- `drawbar_rear` × 1
- `keel_roller_bracket_front` × 1
- `rear_accessory_crossmember` × 1

## trailer_petg_plate_02.3mf

Fysiske platefaner: 2

- `bogie_arm` × 2
- `crossmember_joint_plate_mid` × 4
- `crossmember_joint_plate_rear` × 4
- `drawbar_front` × 1
- `frame_rail_middle` × 2
- `license_plate_holder` × 1
- `rear_light_lens` × 2
- `splice_plate` × 1
- `tandem_fender` × 2
- `v_rail_joint_plate` × 3
- `winch_crank` × 1

## trailer_petg_plate_03.3mf

Fysiske platefaner: 2

- `bogie_mount` × 2
- `coupler_mount_adapter` × 1
- `crossmember_mid` × 1
- `frame_rail_rear` × 2
- `rear_light_housing` × 2
- `side_double_roller_cradle` × 4
- `side_roller_wobble_holder` × 3
- `side_support_post_rear` × 1
- `side_support_receiver` × 4
- `splice_plate` × 1
- `v_rail_joint_plate` × 1
- `winch_tower_body` × 1

## trailer_petg_plate_04.3mf

Fysiske platefaner: 1

- `fender_mount_bracket` × 2
- `keel_roller` × 4
- `keel_roller_bracket_front` × 1
- `keel_roller_bracket_mid_front` × 2
- `keel_roller_bracket_mid_rear` × 2
- `keel_roller_bracket_rear` × 2
- `side_roller_wobble_holder` × 5
- `side_support_post_front` × 2
- `side_support_post_rear` × 1
- `side_support_roller` × 8
- `wheel_hex_adapter` × 4
- `winch_drum` × 1

## trailer_tpu_plate_01.3mf

Fysiske platefaner: 1

- `bow_stop` × 1

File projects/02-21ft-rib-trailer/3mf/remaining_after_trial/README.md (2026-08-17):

# Restutskrift etter prøveprint

Forutsetning: Begge faner i gamle PETG-prosjekt 01 og 02 er printet. Av gamle PETG-prosjekt 03 er bare fysisk fane 1 printet, men `winch_tower_body` mangler fysisk. TPU-baugstoppen regnes som ikke printet.

Settet inneholder uprintede deler og alle tidligere printede deler som ble foreldet av skjøte-/sidestøtteredesignet. Det er ikke en komplett henger nummer to.

## Plateinnhold

A1, 256 × 256 mm. Antallene dekker én komplett henger.
Prosjektfilene inneholder totalt 6 fysiske platefaner.

## remaining_petg_plate_01.3mf

Fysiske platefaner: 2

- `drawbar_rear` × 1
- `frame_rail_middle` × 1
- `rear_accessory_crossmember` × 1
- `rear_light_lens` × 2

## remaining_petg_plate_02.3mf

Fysiske platefaner: 1

- `crossmember_joint_plate_rear` × 2
- `drawbar_front` × 1
- `fender_mount_bracket` × 1
- `frame_rail_middle` × 1
- `keel_roller_bracket_mid_rear` × 2
- `keel_roller_bracket_rear` × 2
- `license_plate_holder` × 1
- `side_double_roller_cradle` × 2
- `side_roller_wobble_holder` × 1
- `side_support_post_front` × 1
- `side_support_post_rear` × 1
- `side_support_roller` × 1

## remaining_petg_plate_03.3mf

Fysiske platefaner: 2

- `coupler_mount_adapter` × 1
- `crossmember_joint_plate_mid` × 4
- `crossmember_joint_plate_rear` × 2
- `crossmember_mid` × 1
- `frame_rail_rear` × 2
- `side_double_roller_cradle` × 2
- `side_roller_wobble_holder` × 7
- `side_support_post_front` × 1
- `side_support_post_rear` × 1
- `side_support_roller` × 7
- `v_rail_joint_plate` × 4
- `winch_tower_body` × 1

## remaining_tpu_plate_01.3mf

Fysiske platefaner: 1

- `bow_stop` × 1

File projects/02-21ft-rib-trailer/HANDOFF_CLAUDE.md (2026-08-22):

# Overlevering til Claude – 21 ft RIB-henger

Oppdatert: 2026-08-22. Dette dokumentet er skrevet for å kunne fortsette arbeidet på en annen PC uten tilgang til den opprinnelige chatten.

## Repository og Git-status

- GitHub: `https://github.com/MrBoggi/3d-boats.git`
- Standardgren: `main` (ikke `master`).
- Trailerprosjekt: `projects/02-21ft-rib-trailer/`.
- Båtreferanse: `projects/01-21ft-rib/`.
- PR #1 med hovedprosjektet er merget til `main` som commit `fccb6a9`.
- Etter merge ble grenen `agent/add-trailer-fit-test-plate` opprettet for testpakken og siste rettelser. Se siste Git-logg for aktuell commit etter checkout.

## Brukerens mål og prioriteringer

Det bygges en printbar 1:10 boggihenger for prosjekt 01 sin 21-fots RIB. Båten, originalmotoren og vei-referansen vises i `assembly.scad`. Brukeren prioriterer nå å unngå mer bortkastet PETG etter at første store prøveutskrift viste at frontdelene ikke fysisk kunne monteres, selv om hullene så riktige ut digitalt.

Viktig skille:

1. Lokal klaring/passform i en skjøt.
2. At store deler faktisk har riktig totallengde, vinkel, hullplassering og monteringsrekkefølge.

Brukeren er mest bekymret for punkt 2. Ikke be brukeren printe `3mf/remaining_after_trial/` før både lokal skjøtetest og en fullskala, materialbesparende ramme-/alignment-test er fysisk godkjent.

## Designstatus

Hengeren har blant annet:

- todelt V-front;
- parallelle hovedvanger;
- boggiarmer, kjøpehjul og sekskantadaptere;
- fire V-formede kjølruller;
- fire doble, leddede siderullestøtter;
- buede tandemskjermer med tett innside;
- vinsjtårn, trommel, sveiv og vippbar TPU V-baugstopp;
- fremre kjøpeadapter for omtrent 6 mm RC-kule;
- baklys på bjelken foran motorens åpne sone og sideforskjøvet skiltplate;
- original båtmotor og vei som klaringsreferanser.

Alle hovedmål og klaringer ligger i `scad/config.scad`. Produksjonssammenstillingen ligger i `scad/assembly.scad`; ikke dupliser mål i nye moduler.

## Viktige skjøteredign

Første fysiske prøveprint avslørte at `drawbar_front` og `drawbar_rear` var to massive bjelker i samme volum. Hullene fluktet, men delene kunne bare legges oppå hverandre. Dette er rettet til komplementære halv-i-halv-skjøter med nominell 0,3 mm vertikal printklaring og to M3-bolter per V-arm.

Andre korrigeringer:

- koblingsadapteren har halv-i-halv-tunge mot senterbjelken;
- midtbjelken stopper 0,3 mm innenfor vangene og bruker egne plater over og under;
- bakre lysbjelke starter 0,3 mm bak vangeendene og bruker egne plater over og under;
- kun utvendige lasker brukes ved vangskjøten ved X = 440 mm;
- siderullestøtten har rundt hovedpivotnav i gaffel og egen sekundærpivot per rulle;
- vuggehullet ble flyttet 0,2 mm for å unngå tangent/non-manifold toppflate.

Under utvikling av fit-testen ble enda en reell produksjonsfeil funnet: V-armene ble unionert over adapterens to M3-hull og fylte dem igjen. `scad/frame.scad` er nå rettet slik at hullene skjæres gjennom den komplette frontunionen. `drawbar_front.stl`, enkelt-3MF og berørte plateprosjekter er regenerert.

## Digital validering

Reproduksjonskommando:

```bash
projects/02-21ft-rib-trailer/scripts/check_joint_interfaces.sh
```

Siste kjente resultat:

- 35/35 produksjonsdeler er ikke-tomme og `Simple: yes`;
- 8/8 kritiske kollisjonsmoduler gir tom interseksjon;
- fit-testplaten slicer med returkode 0, 18 objekter og ingen advarsler;
- alle fire `remaining_after_trial`-prosjektene slicer med returkode 0 og ingen advarsler.

OpenSCAD finnes på verten og kan kjøres med `flatpak-spawn --host openscad`. Bambu Studio er Flatpak `com.bambulab.BambuStudio`. Miljøet kan vise en ufarlig OpenGL/GLFW-feil i headless modus selv om 3MF-filen blir skrevet; verifiser alltid filstørrelse og slicerapport.

## Fit-testpakken på aktuell gren

Filer:

- `3mf/fit_tests/fit_test_plate_01.3mf`;
- `3mf/fit_tests/README.md`;
- `scad/fit_tests.scad`;
- `scripts/build_fit_test_plate.py`;
- `stl/fit_tests/`.

Pakken har én A1-fane med 18 objekter og tester i full skala:

- V-frontens halv-i-halv-skjøt;
- adaptertunge og begge M3-hull;
- vangskjøt og utvendig lask;
- midtbjelke med over-/underplate;
- bakre lysbjelke med over-/underplate;
- hoved- og sekundærpivot i siderullestøtten.

Kupongene er klippet direkte fra produksjonsmodulene. Mål, hull og anleggsflater skal derfor være identiske. Testen skal monteres med reelle M3-skruer, skiver og muttere.

Denne platen tester lokale grensesnitt. Den løser ikke alene brukerens hovedbekymring om global geometri i de store delene.

## Neste anbefalte konstruksjonsoppgave

Lag et separat fullskala `frame_alignment_test` med lavt materialforbruk:

- hele V-fronten i korrekt lengde og vinkel;
- hele hovedvangene;
- hele fremre, midtre og bakre tverrbjelke;
- alle produksjonshull og alle nødvendige festeplater;
- full produksjonstykkelse bare lokalt rundt skjøter/hull;
- 2–3 mm tynne ribber eller web mellom skjøteområdene.

Målet er at hele rammen kan skrus sammen på et bord og avsløre feil lengde, vinkel, sidevalg, hullplassering eller monteringslogikk med vesentlig mindre plast enn massive produksjonsdeler. Bruk faktisk produksjonsgeometri og delte parametere; ikke tegn uavhengige kopier.

Brukeren vil gjerne prøve dette i billig PLA. Valgt kandidat er Flashforge PLA Pro 1,75 mm fra Clas Ohlson, artikkel 39-1771. Det er egnet til geometrisk kontroll. Bruk samme dyse, laghøyde og veggrekkefølge som produksjonen, omtrent 210 °C dyse, 55–60 °C plate og maks omtrent 60 mm/s. Kritiske endelige klaringer skal likevel bekreftes med små PETG-kuponger. PLA-testen er ikke en styrketest.

## Fysisk utskrift som allerede er gjort

Brukerens opplysning:

- begge fysiske faner i gamle PETG-prosjekt 01 er printet;
- begge fysiske faner i gamle PETG-prosjekt 02 er printet;
- bare første fysiske fane i gamle PETG-prosjekt 03 er printet;
- vinsjtårnet manglet fysisk, selv om gammel 3MF-metadata plasserte det på fane 1;
- TPU-baugstopp er behandlet som ikke printet med mindre brukeren sier noe annet.

Deler som kan beholdes og brukes:

- 2 boggiarmer;
- 2 boggifestebraketter;
- 2 tandemskjermer;
- 1 skjermfeste (ett til mangler);
- 4 hjulsekskantadaptere;
- 4 kjølruller;
- 2 fremre kjølrullebraketter;
- 2 midt-fremre kjølrullebraketter;
- 4 sidestøttemottakere;
- 2 baklyshus;
- 1 vinsjtrommel;
- 1 vinsjsveiv;
- 2 skjøtelasker;
- 1 standard fremre tverrbjelke.

Reservedeler:

- 2 ekstra skjøtelasker;
- 1 ekstra gammel standardtverrbjelke, som ikke erstatter den nye korte `crossmember_mid`.

Gamle print som ikke skal brukes i revidert sammenstilling:

- `drawbar_front` og `drawbar_rear`;
- 2 `frame_rail_middle` og 2 `frame_rail_rear`;
- gammel `rear_accessory_crossmember`;
- gammel `coupler_mount_adapter`;
- 4 gamle `side_double_roller_cradle`;
- 8 gamle `side_roller_wobble_holder`.

## Restutskriftssett

`3mf/remaining_after_trial/` inneholder 54 PETG-deler og én TPU-del fordelt på seks fysiske faner. Det ble beregnet fra utskriftshistorikken over og inkluderer uprintede samt redesignede deler. `winch_tower_body` er eksplisitt inkludert.

Dette settet er digitalt gyldig, men skal regnes som blokkert til testene er fysisk godkjent. Hvis modeller endres etter test, må individuelle STL/3MF, fullplater og restplater regenereres; ikke la gamle binærfiler bli liggende.

## Print- og materialstrategi

Produksjonsprofilen i 3MF er i hovedsak:

- Bambu Lab A1, 0,4 mm dyse, 0,20 mm lag;
- Generic PETG;
- 4 vegger;
- 5 topp- og bunnlag;
- 35 % gyroid;
- `normal(auto)` støtte på fullplatene der nødvendig;
- TPU for baugstoppen.

Produksjons-PETG er ikke strukturelt lasttestet. Hengeren skal ikke merkes ferdig før fysisk lasttest, klaringstest, motor-/bakkeklaring og faktisk kuletrykk er dokumentert.

## Kjøpekomponenter og maskinvare

README-en er autoritativ for lenker og konvolutter. Viktige valg:

- kjøpehjul omtrent 65 mm diameter, 27 mm bredde, 12 mm sekskant og M4 akselmutter;
- kjøpt RC-kobling for omtrent 5,8–6,0 mm kule, M3-grensesnitt;
- øvrige rammeskjøter og pivoter hovedsakelig M3;
- baugøye tilhører båtprosjektet, ikke hengeren;
- vinsjstroppen er en 1:10 mockup og skal ikke detaljstyre rammegeometrien uten mål på faktisk produkt.

## Arbeidsregler for videreføring

1. Les `.codex/skills/openscad-modeling/SKILL.md` og prosjektets README før endringer.
2. Bevar parametrisk kilde; ikke patch bare STL/3MF.
3. Enhver produksjonsendring skal etterfølges av alle relevante STL- og 3MF-eksporter.
4. Rendér hver endret del med CGAL og krev `Simple: yes`.
5. Legg til eksplisitt kollisjonsmodul eller fysisk kupong for nye grensesnitt.
6. Ikke anta at hull som flukter betyr at delene kan monteres; kontroller volum, side, verktøytilgang og monteringsrekkefølge.
7. Ikke be om full PETG-utskrift før billig fullskala alignment-test og små PETG-kuponger er godkjent.
8. Oppdater dette dokumentet og README når fysisk test gir nye mål eller beslutninger.

## Nyttige kommandoer

```bash
cd projects/02-21ft-rib-trailer
./build.sh --approved
python3 scripts/build_fit_test_plate.py
python3 scripts/build_plate_3mf.py
python3 scripts/build_remaining_after_trial.py
scripts/check_joint_interfaces.sh
```

Se `3mf/fit_tests/README.md`, `3mf/remaining_after_trial/README.md` og hoved-README for nøyaktig plateinnhold og monteringsinstruksjoner.

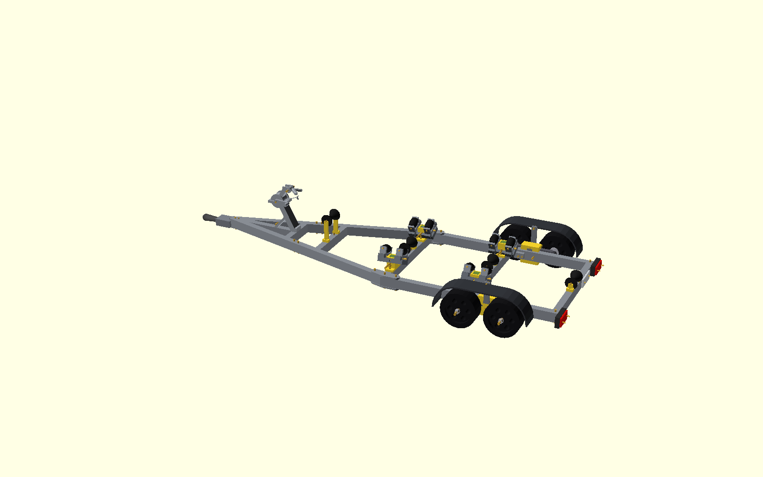
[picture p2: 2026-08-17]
projects/02-21ft-rib-trailer/png/review_service_access.png

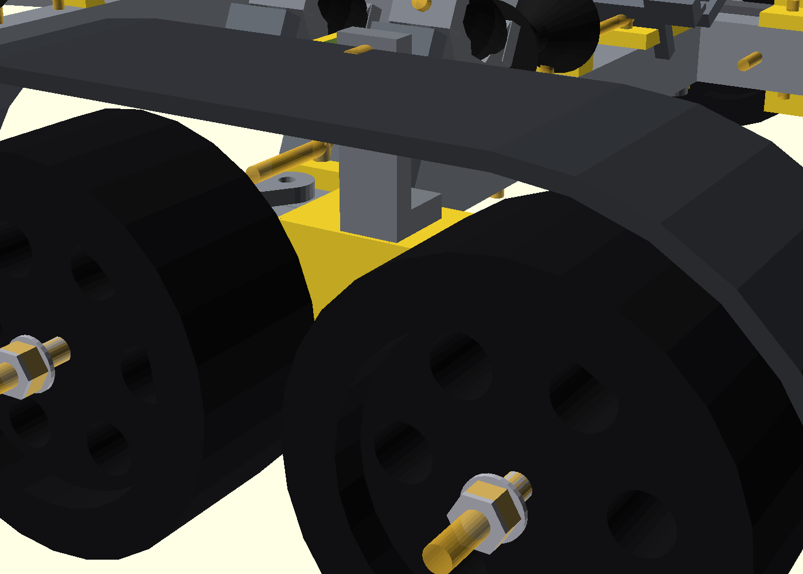
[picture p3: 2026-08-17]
projects/02-21ft-rib-trailer/png/review_service_bogie.png

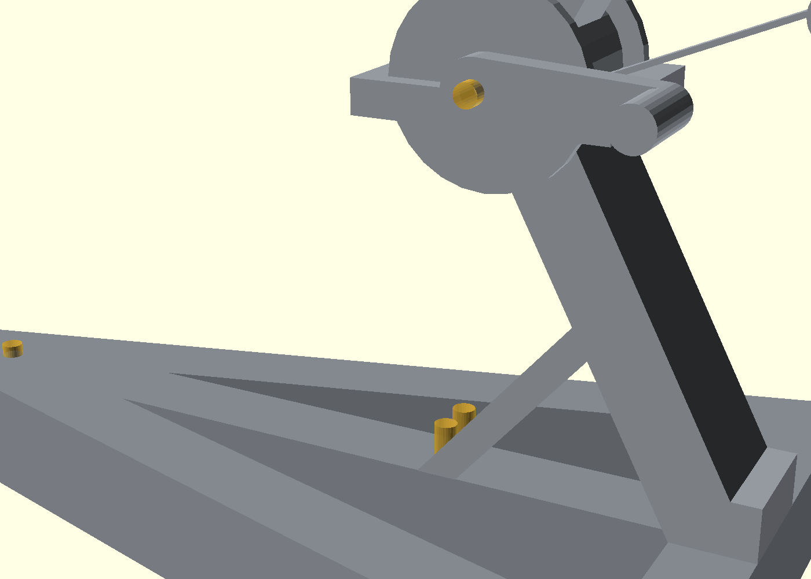
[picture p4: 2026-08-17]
projects/02-21ft-rib-trailer/png/review_service_winch.png

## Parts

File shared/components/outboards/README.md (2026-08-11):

# Shared outboard references

## Printables 1191848 — RC Outboard Motor 1/10

Reusable, unmodified third-party reference for boat projects.

- Creator: NoMatter
- Source: https://www.printables.com/model/1191848-rc-outboard-motor-110
- Reported license: CC BY-NC-ND
- Motor: water-cooled 2948 brushless motor
- Transmission: 0.5 module, 12-tooth, 3 mm bevel gears
- Bearings: 603 (3 × 9 × 3 mm)

The original files are not stored in Git. Download and extract them to:

```text
vendor/printables-1191848/
└── rc-outboard-motor-110-model_files/
    ├── cover_02.stl
    ├── lowerbody_02.stl
    └── ...
```

Do not edit, scale, rename, or redistribute the source STLs. Project-specific
transom plates, adapters, servo links, and placement transforms belong in each
boat project.

The wrapper `printables_1191848.scad` imports the original parts at their
native scale and shared CAD coordinates. It also provides a dependency-free
clearance envelope for projects that do not have the vendor files installed.

## Verified reference datums

The native STL assembly has been recentered and mapped to boat coordinates:

- Boat X: motor forward direction
- Boat Y: starboard
- Boat Z: up
- Required orientation from native STL: rotate -90 degrees around Z
- Reference steering axis: X/Y = 0/0
- Propeller shaft level: Z = -55 mm
- Anticavitation plate reference: Z = -28 mm

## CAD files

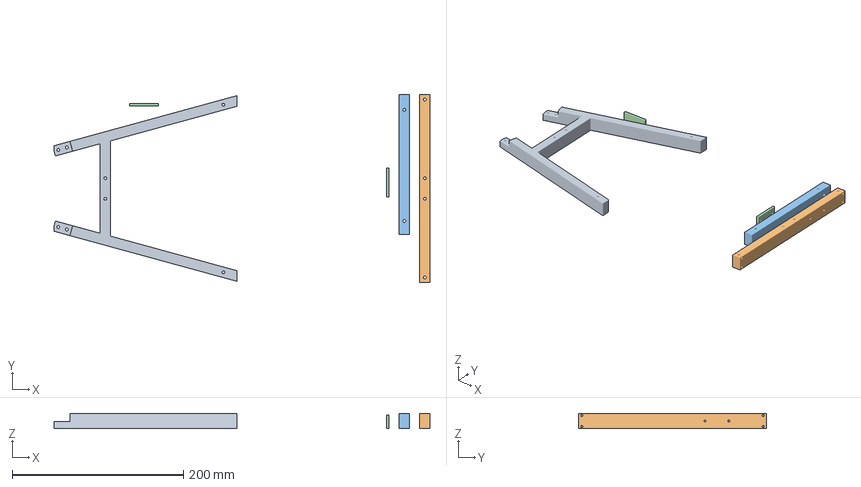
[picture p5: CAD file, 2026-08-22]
projects/02-21ft-rib-trailer/3mf/remaining_after_trial/remaining_petg_plate_01.3mf
439.7 x 220.0 x 18.0 mm
drawbar_rear.stl
rear_accessory_crossmember.stl
frame_rail_middle.stl
rear_light_lens.stl x 2

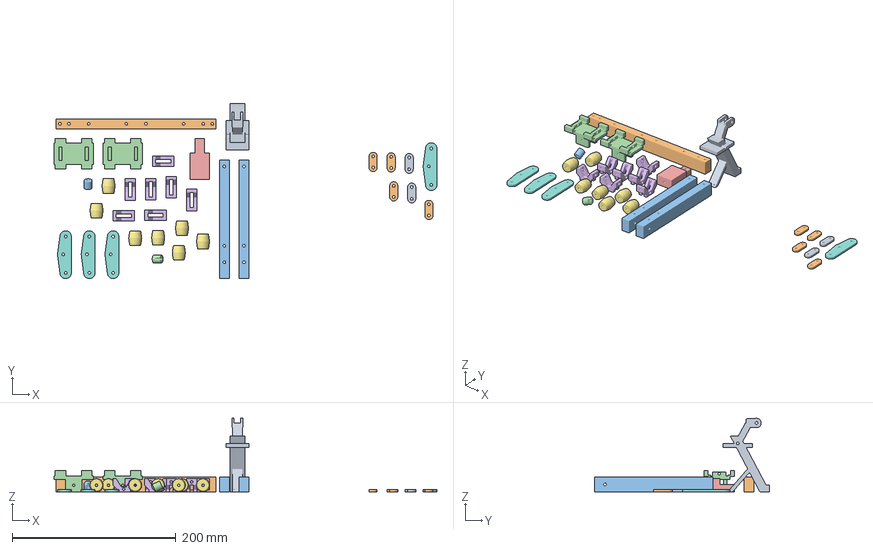
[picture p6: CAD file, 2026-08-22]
projects/02-21ft-rib-trailer/3mf/remaining_after_trial/remaining_petg_plate_03.3mf
467.7 x 214.0 x 89.9 mm
winch_tower_body.stl
crossmember_mid.stl
frame_rail_rear.stl x 2
side_double_roller_cradle.stl x 2
coupler_mount_adapter.stl
side_roller_wobble_holder.stl x 7
side_support_roller.stl x 7
v_rail_joint_plate.stl x 4
crossmember_joint_plate_rear.stl x 2
crossmember_joint_plate_mid.stl x 4
side_support_post_rear.stl
side_support_post_front.stl

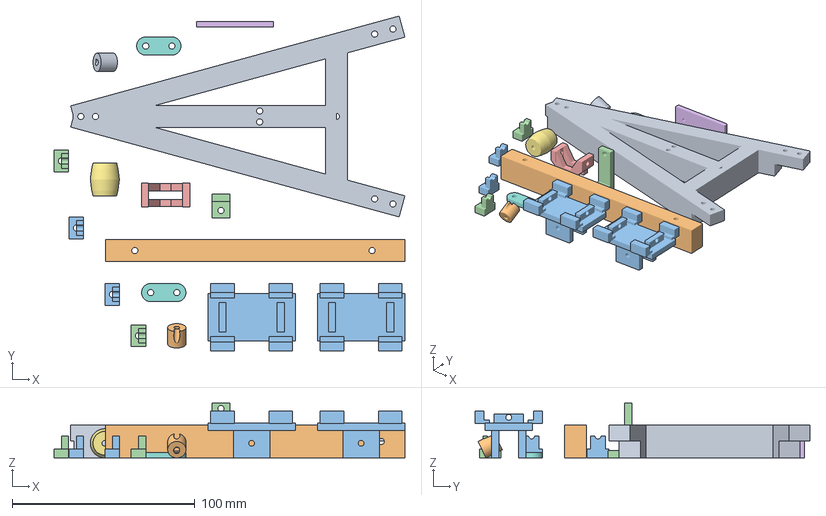
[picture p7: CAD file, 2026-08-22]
projects/02-21ft-rib-trailer/3mf/remaining_after_trial/remaining_petg_plate_02.3mf
192.3 x 183.5 x 30.0 mm
drawbar_front.stl
frame_rail_middle.stl
side_double_roller_cradle.stl x 2
fender_mount_bracket.stl
side_roller_wobble_holder.stl
license_plate_holder.stl
side_support_roller.stl
crossmember_joint_plate_rear.stl x 2
side_support_post_rear.stl
side_support_post_front.stl
keel_roller_bracket_mid_rear.stl x 2
keel_roller_bracket_rear.stl x 2

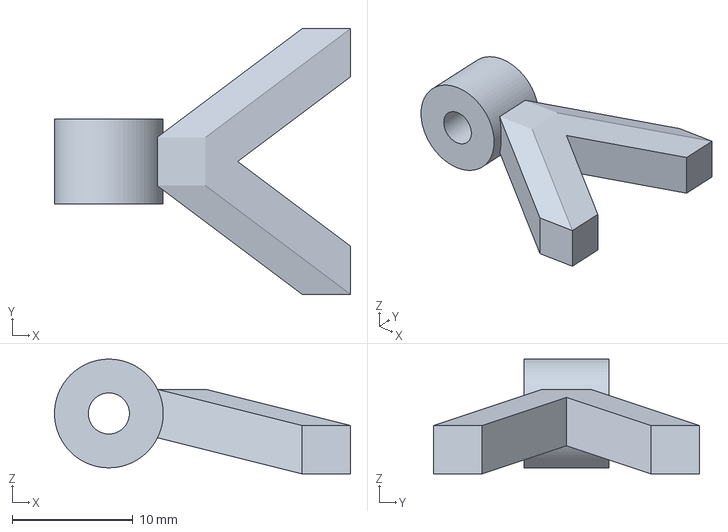
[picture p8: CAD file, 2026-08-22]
projects/02-21ft-rib-trailer/3mf/remaining_after_trial/remaining_tpu_plate_01.3mf
24.5 x 22.0 x 9.50 mm

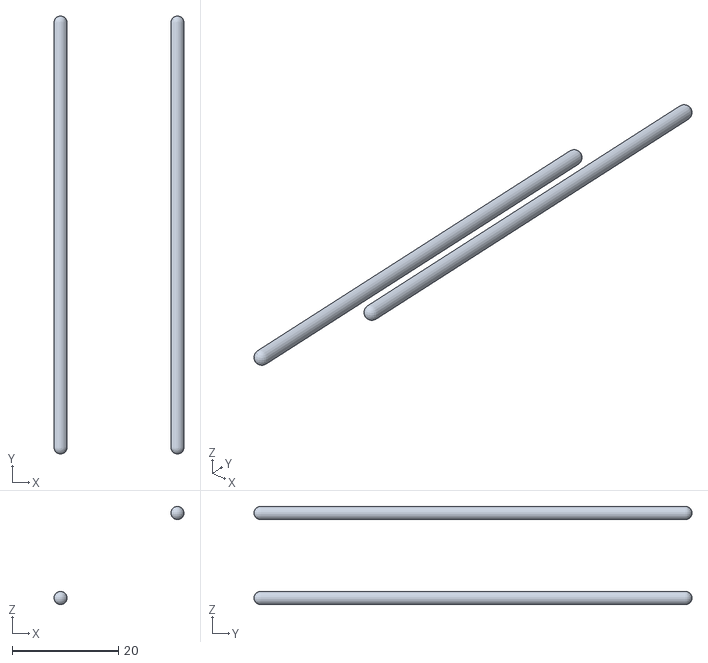
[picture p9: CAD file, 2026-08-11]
projects/01-21ft-rib/stl/helm_bench_cross_braces.stl
24.5 x 82.5 x 18.5

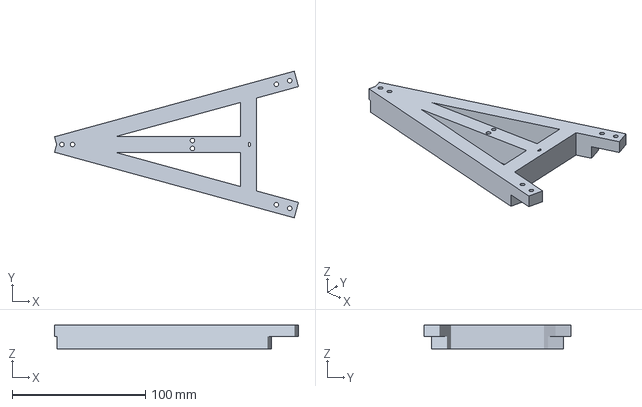
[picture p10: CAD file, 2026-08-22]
projects/02-21ft-rib-trailer/3mf/drawbar_front.3mf
183.2 x 110.1 x 18.0 mm

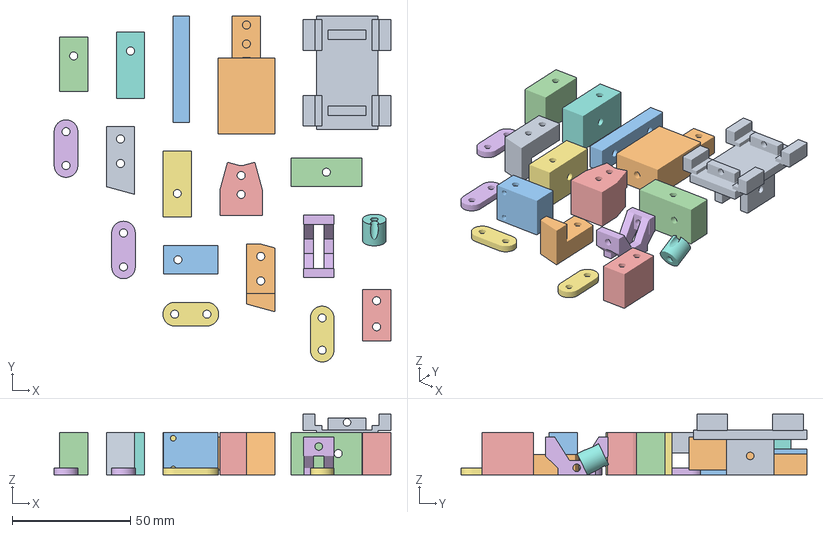
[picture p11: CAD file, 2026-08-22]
projects/02-21ft-rib-trailer/3mf/fit_tests/fit_test_plate_01.3mf
142.2 x 146.2 x 25.7 mm
side_double_roller_cradle.stl
coupler_mount_adapter.stl
splice_plate.stl
fit_mid_rail.stl
fit_coupler_frame.stl
side_roller_wobble_holder.stl
fit_splice_front.stl
fit_splice_rear.stl
fit_v_front.stl
fit_v_rear.stl
fit_rear_crossmember.stl
fit_rear_rail.stl
fit_mid_crossmember.stl
crossmember_joint_plate_rear.stl x 2
crossmember_joint_plate_mid.stl x 2
fit_side_post_head.stl

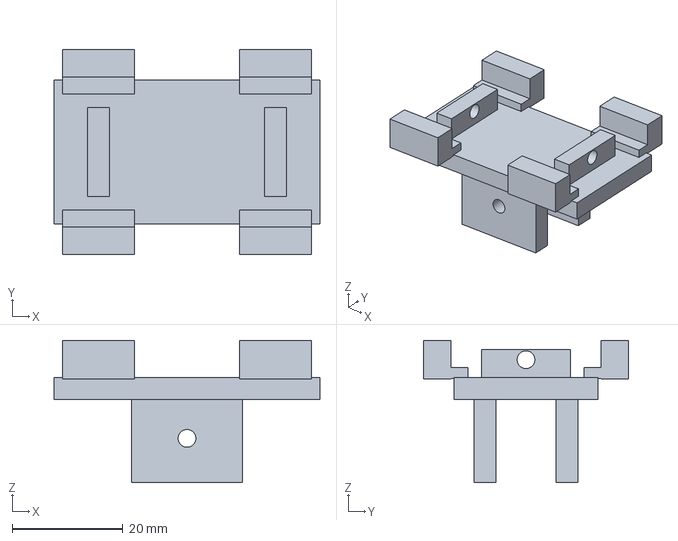
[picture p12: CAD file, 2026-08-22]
projects/02-21ft-rib-trailer/3mf/fit_tests/parts/side_double_roller_cradle.3mf
48.0 x 37.0 x 25.7 mm

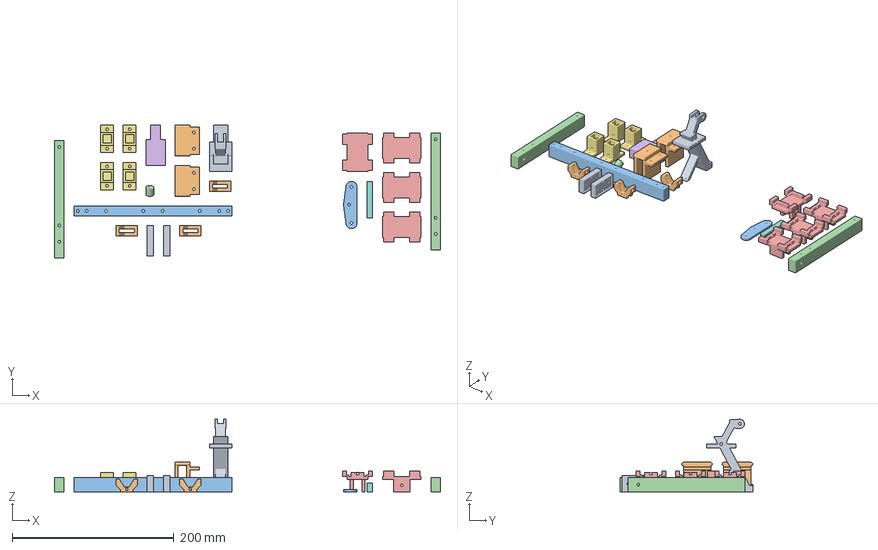
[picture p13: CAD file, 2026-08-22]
projects/02-21ft-rib-trailer/3mf/plates/trailer_petg_plate_03.3mf
477.4 x 164.0 x 89.9 mm
winch_tower_body.stl
bogie_mount.stl x 2
crossmember_mid.stl
frame_rail_rear.stl x 2
side_double_roller_cradle.stl x 4
coupler_mount_adapter.stl
side_support_receiver.stl x 4
splice_plate.stl
rear_light_housing.stl x 2
side_roller_wobble_holder.stl x 3
v_rail_joint_plate.stl
side_support_post_rear.stl

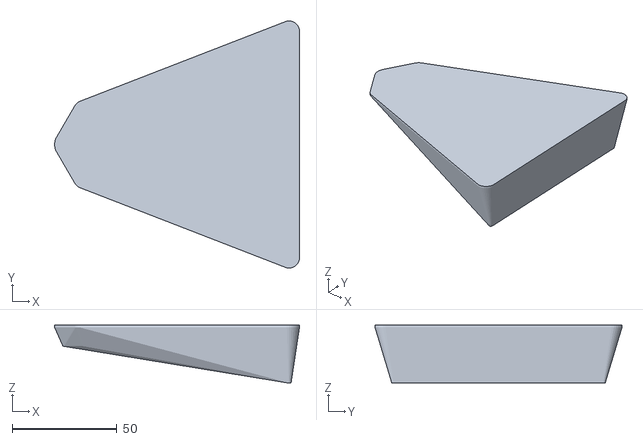
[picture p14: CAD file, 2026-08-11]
projects/01-21ft-rib/stl/bow_locker_base.stl
117.0 x 118.0 x 27.5

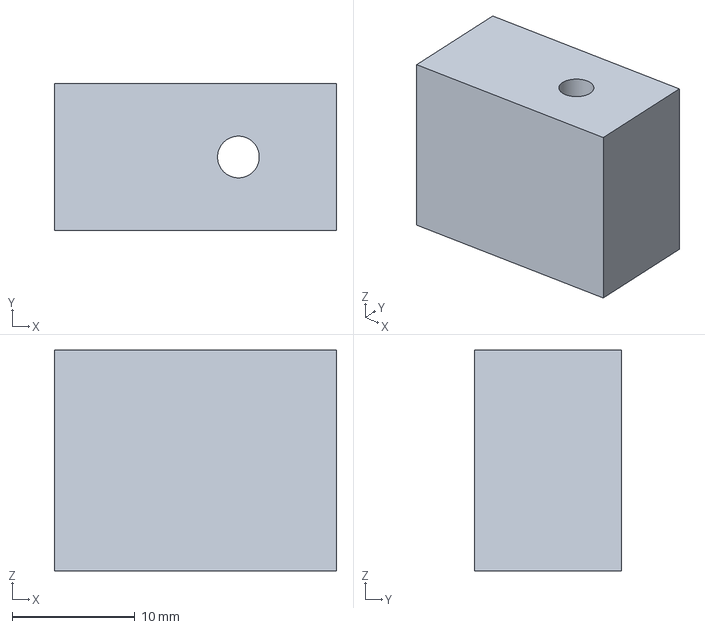
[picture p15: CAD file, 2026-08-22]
projects/02-21ft-rib-trailer/3mf/fit_tests/parts/fit_rear_rail.3mf
23.0 x 12.0 x 18.0 mm

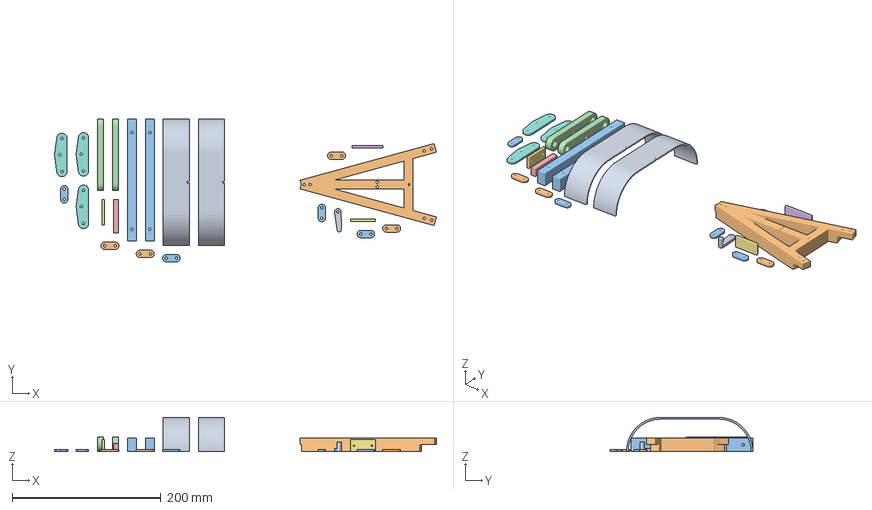
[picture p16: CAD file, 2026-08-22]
projects/02-21ft-rib-trailer/3mf/plates/trailer_petg_plate_02.3mf
512.9 x 191.8 x 45.9 mm
tandem_fender.stl x 2
drawbar_front.stl
frame_rail_middle.stl x 2
bogie_arm.stl x 2
splice_plate.stl
license_plate_holder.stl
rear_light_lens.stl x 2
v_rail_joint_plate.stl x 3
winch_crank.stl
crossmember_joint_plate_rear.stl x 4
crossmember_joint_plate_mid.stl x 4

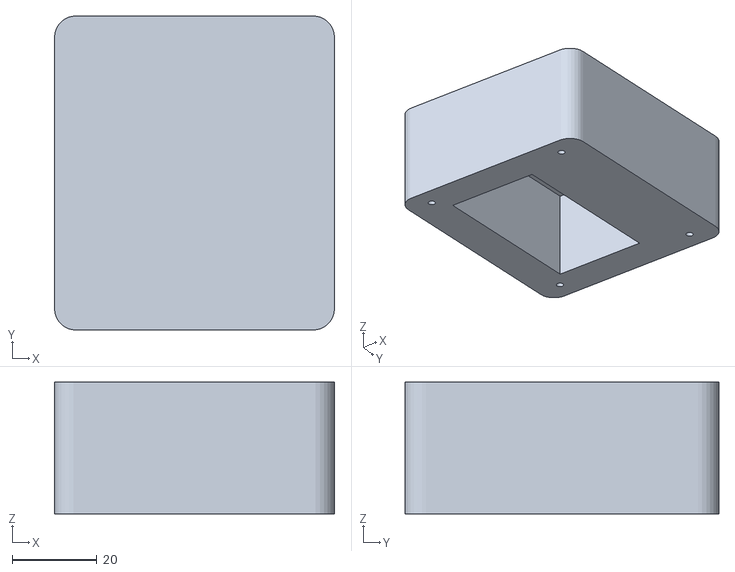
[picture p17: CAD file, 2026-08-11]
projects/01-21ft-rib/stl/aft_bench_servo_cover.stl
66.0 x 73.9 x 31.0

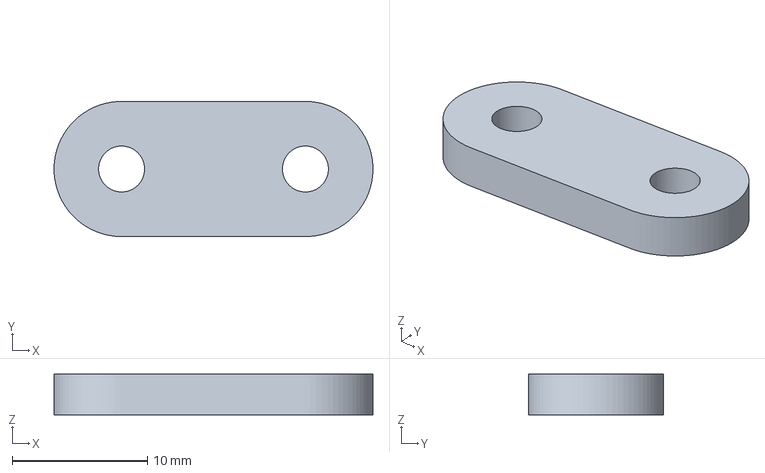
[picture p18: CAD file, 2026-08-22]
projects/02-21ft-rib-trailer/3mf/fit_tests/parts/crossmember_joint_plate_mid.3mf
23.6 x 10.00 x 3.00 mm

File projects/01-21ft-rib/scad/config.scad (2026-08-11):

// 21 ft RIB at 1:10 scale. All dimensions are millimetres.
// Coordinate system: X bow->stern, Y port->starboard, Z keel->up.
project_scale_denominator = 10;
boat_length = 660;
boat_width = 252;
hull_deck_z = 62;
wall_thickness = 2.8;
pontoon_radius = 25;
quality = $preview ? 28 : 72;
boolean_overlap = 0.2;

// Bambu Lab A1: keep exported bounding boxes below 256 mm per axis.
printer_x = 256;
printer_y = 256;
printer_z = 256;
section_bow_end = 220;
section_mid_end = 430;

// Assembly and glue clearances.
joint_land = 8;
glue_gap = 0.25;
fastener_clearance = 0.25;
joint_bulkhead_thickness = 3;
joint_socket_back_wall = 2.8;
joint_socket_wall = 2.8;
joint_center_key_yz = [12, 10];
joint_side_key_yz = [8, 5];
joint_side_key_y = 48;
joint_key_lead_in = 0.6;
joint_preview_gap = 12;

// Component clearance envelopes, not product dimensions.
motor_envelope = [65, 35, 45];
esc_envelope = [80, 50, 35];
servo_envelope = [42, 22, 38];
battery_envelope = [150, 50, 35];
receiver_envelope = [55, 35, 25];
ubec_envelope = [45, 25, 15];

// Selected component bodies and Stage 1 cockpit-floor clearances.
selected_battery_size = [106, 34, 22];
selected_esc_size = [60.5, 38.5, 25.6];
floor_battery_clearance = [112, 40, 28];
floor_esc_clearance = [68, 44, 31];
floor_receiver_clearance = [60, 40, 25];
cockpit_floor_z = 55;
cockpit_floor_thickness = 3;
cockpit_floor_hatch_gap = 0.3;
cockpit_floor_support_width = 5;
cockpit_floor_support_height = 4;
cockpit_floor_aft_limit = 592;
battery_hatch_center = [348, 16];
battery_hatch_size = [182, 100];

// Stage 1 console shell, mounted to the removable battery hatch.
// Each section is [Z, bow X, helm X, Y width, corner radius,
// front curvature depth].
console_sections = [
    [cockpit_floor_z, 297, 350, 84, 8, 10],
    [63, 297, 350, 84, 8, 10],
    [70, 293, 341, 74, 8, 10],
    [82, 295, 347, 72, 8, 9],
    [110, 299, 331, 70, 7, 8],
    [120, 300, 324, 70, 6, 7],
    [126, 301, 321, 70, 5, 6],
    [130, 305, 321, 70, 3, 5]
];
console_width = 82;
console_top_width = 70;
console_wall_thickness = 2.6;
console_profile_rounding = 4;
console_base_size = [53, 84, 15];
console_base_corner_radius = 8;
console_base_flange_width = 5;
console_center_y = 20;
console_port_passage_min = 44;
console_dashboard_lower = [345, 86];
console_dashboard_upper = [321, 128];
console_dashboard_width = 62;
console_dashboard_recess_lower = [342, 90];
console_dashboard_recess_upper = [322, 124];
console_dashboard_recess_width = 54;
console_dashboard_recess_corner_diameter = 6;
console_dashboard_recess_depth = 10;
console_dashboard_anchor_overlap = 4;
console_steering_wheel_diameter = 17;
console_steering_wheel_rim_diameter = 1.8;
console_throttle_size = [5.5, 9, 11]; // depth, width, height
console_throttle_panel_center = [-2, 8]; // lateral, vertical
console_oled_pcb_size = [5, 27.8, 27.3]; // depth, width, height
console_oled_active_size = [21.74, 11.2]; // width, height
console_oled_window_size = [22.5, 12];
console_oled_panel_center = [12.5, 22.5]; // lateral, vertical
console_oled_window_corner_radius = 1.2;
console_oled_mount_boss_diameter = 5.2;
console_oled_mount_pilot_diameter = 1.3; // M1.6 thread-forming screw
console_oled_mount_offsets = [16, 10]; // lateral, vertical
console_oled_retainer_thickness = 2;
console_oled_retainer_edge_overlap = 1.2;
console_oled_retainer_clearance = 0.4;
console_windshield_front_lower = [306, 130];
console_windshield_front_upper = [312, 174];
console_windshield_curve_depth = 5;
console_windshield_rear_lower = [321, 130];
console_windshield_rear_upper = [327, 174];
console_windshield_front_half_width = 34;
console_windshield_rear_half_width = 35;
console_frame_half_width = 39;
console_hoop_half_width = 38;
console_frame_diameter = 4.5;
console_screen_tab_diameter = 2.2;
console_frame_lower_anchor = [310, 78];
console_frame_shoulder = [319, 110];
console_hoop_tenon_diameter = 3.2;
console_hoop_tenon_length = 5;
console_hoop_socket_clearance = 0.3;
console_hoop_socket_boss_diameter = 7;
console_hoop_lock_pilot_diameter = 1.3;
console_design_locked = true;

// Stage 1 removable two-person helm bench.
helm_bench_center_x = 417;
helm_bench_center_y = console_center_y;
helm_bench_seat_size = [33, 88, 6];
helm_bench_seat_corner_radius = 4;
helm_bench_seat_top_z = 100;
helm_bench_frame_spacing = 80;
helm_bench_frame_thickness = 2.4;
helm_bench_tube_diameter = 2.5;
helm_bench_foot_size = [10, 8, 2];
helm_bench_foot_x_offsets = [-12, 12];
helm_bench_hatch_edge_clearance = 2;
helm_bench_floor_pilot_diameter = 2.2;
helm_bench_foot_hole_spacing_x = 4.5;
helm_bench_floor_insert_diameter = 4.0;
helm_bench_floor_insert_depth = 4.0;

// Stage 1 removable aft bench and steering-servo service cover.
aft_seat_center = [540, 0];
aft_seat_center_cushion_size = [48, 72, 7];
aft_seat_cushion_top_z = 90;
aft_seat_back_center_x = 570;
aft_seat_center_back_size = [7, 72, 30];
aft_seat_wing_back_size = [7, 22, 27];
aft_seat_back_angle = -8;
aft_seat_cover_size = [66, 74, 31];
aft_seat_cover_center = [553, 0, 70.5];
aft_seat_cover_wall = 3;
aft_seat_service_clearance = [30, 52, 27];
aft_seat_mount_x = [528, 577];
aft_seat_mount_y = [-31, 31];
aft_seat_mount_pilot_diameter = 2.2;
aft_seat_insert_diameter = 4.0;
aft_seat_insert_depth = 4.0;
aft_bench_design_locked = true;

// Stage 1 bow locker/seat and removable pontoon-following railings.
bow_bench_center_x = 87.5;
bow_bench_top_z = 90;
bow_bench_cushion_thickness = 6;
bow_bench_base_bottom_z = cockpit_floor_z;
bow_bench_base_top_z = bow_bench_top_z - bow_bench_cushion_thickness;
// The bow locker follows the rising foredeck instead of hanging below it.
bow_bench_base_forward_bottom_z = 75;
bow_bench_base_aft_bottom_z = 57.5;
bow_bench_forward_half_width = 16;
bow_bench_aft_half_width = 54;
bow_bench_forward_x = 32;
bow_bench_aft_x = 130;
bow_bench_corner_radius = 5;
bow_bench_nose_x = 25;
bow_bench_nose_radius = 7;
bow_deck_height = 7;
bow_deck_corner_radius = 2.2;
bow_rail_foot_xy = [198, 59];
// From the molded floor shoulder, across the upper-inner pontoon quadrant,
// along the pontoon sheer and finally into the anchor-roller cheek.
bow_rail_path = [
    [198, 55, 76],
    [190, 60, 84],
    [178, 67, 92],
    [160, 70, 98],
    [130, 64, 104],
    [100, 55, 109],
    [70, 43, 112],
    [45, 34, 114],
    [30, 27, 117],
    [25, 20, 118]
];
bow_rail_diameter = 2.6;
bow_rail_tenon_diameter = 2.0;
bow_rail_tenon_length = 4;
bow_rail_socket_clearance = 0.25;

// Approved Printables 1191848 Mount 0 interface.
stern_mount_design_locked = true;
mount0_hole_spacing_y = 32.69;
mount0_hole_spacing_z = 22.31;
mount0_vendor_hole_diameter = 3.28;
mount0_adapter_hole_diameter = 3.6;
mount0_center_clearance_diameter = 16;
mount0_adapter_plate_size = [8, 55, 45];
mount0_transom_tilt_correction = -5;
motor_mount_tilt_correction = -5;
mount0_mounting_face_offset = 7.366;
mount0_insert_pocket_diameter = 4.5;
mount0_insert_pocket_depth = 6.5;
mount0_boss_recess_depth = 5.5;
// Cavitation plate is nominally aligned with the stern keel at Z = 8.
mount0_adapter_center = [598, 0, 36];
mount0_vendor_center = [610.815, 0, 36];
// 21 ft RIB / XL outboard reference datums at 1:10.
reference_tube_diameter = 54;
reference_tube_top_z = 92.5;
reference_tube_center_z =
    reference_tube_top_z - reference_tube_diameter / 2;
reference_beam = 252;
reference_deadrise = 26;
reference_xl_transom_height = 63.5;
pontoon_hull_saddle_radius = 4.5;
target_cavitation_z = 0;
mount_half_height = 32.533 / 2;
mount_center_z = reference_xl_transom_height - mount_half_height;
mount_center_to_cavitation = 18.825;
mount_center_to_propeller = 45.825;
required_leg_extension =
    mount_center_z - mount_center_to_cavitation - target_cavitation_z;
assembly_origin_above_mount = 9.175;

xl_extension_shaft_clearance = 4.0;
// Measured directly from the vendor STL mating planes. The same footprint
// exists at lowerbody Z=323.745 and transmission-case Z=323.764.
xl_adapter_bolt_clearance = 3.4;
xl_adapter_bolt_centers = [
    [-7.304, -20.082],
    [ 7.304, -20.082],
    [-9.450,  11.786],
    [ 9.450,  11.786]
];
xl_adapter_wall = 2.4;
xl_adapter_station_height = 0.35;
xl_adapter_curve_fractions = [0, 0.06, 0.13, 0.25, 0.45, 0.68, 0.84, 0.94, 1];
xl_adapter_curve_offsets = [0, -0.55, -1.20, -1.55, -1.70, -1.55, -1.05, -0.35, 0];
xl_adapter_face_thickness = 3.0;
xl_adapter_bolt_boss_diameter = 7.0;
xl_adapter_shaft_tube_diameter = 9.0;
xl_adapter_design_locked = true;

shaft_tube_diameter = 8.2;
shaft_angle = 9;
steering_angle = 30;
steering_servo_axis = [547, 0, 80];
steering_arm_radius = 18;
steering_linkage_clearance = 2;
motor_steering_bolt_z = 77;
motor_steering_bolt_diameter = 2.4;
motor_steering_bolt_length = 36;
steering_servo_rotation_z = 90;
steering_servo_body_clearance = 0.75;
steering_servo_insert_pocket_diameter = 3.2;
steering_servo_insert_pocket_depth = 3.5;
steering_servo_insert_boss_diameter = 7;
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

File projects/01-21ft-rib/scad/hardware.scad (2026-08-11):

include <config.scad>

module envelope(size, label = "") {
    color([0.15, 0.55, 0.95, 0.45])
        cube(size, center = true);
    if (label != "")
        echo(str(label, " clearance envelope: ", size));
}

module hardware_envelopes() {
    translate([305, 0, 58]) envelope(battery_envelope, "battery");
    translate([500, 0, 58]) rotate([0, 0, 90])
        envelope(motor_envelope, "motor");
    translate([490, -55, 62]) envelope(esc_envelope, "ESC");
    translate([560, 55, 63]) envelope(servo_envelope, "servo");
    translate([405, -52, 62]) envelope(receiver_envelope, "receiver");
    translate([410, 52, 57]) envelope(ubec_envelope, "UBEC");
}

module slotted_tray(size, strap_slots = true) {
    difference() {
        cube([size[0], size[1], 3], center = true);
        if (strap_slots)
            for (x = [-size[0] / 3, size[0] / 3])
                translate([x, 0, 0])
                    cube([5, size[1] - 8, 5], center = true);
    }
    for (y = [-size[1] / 2, size[1] / 2])
        translate([0, y, 4])
            cube([size[0], 2.5, 8], center = true);
}

module equipment_mounts() {
    translate([305, 0, 39]) slotted_tray([155, 55, 3]);
    translate([490, -55, 42]) slotted_tray([85, 55, 3]);
    translate([560, 55, 42]) slotted_tray([48, 28, 3]);
    translate([405, -52, 42]) slotted_tray([60, 40, 3]);

    // Adjustable 2845 motor rails.
    for (y = [-19, 19])
        translate([500, y, 43])
            difference() {
                cube([72, 5, 10], center = true);
                for (x = [-22, 22])
                    translate([x, 0, 0])
                        cube([16, 7, 4], center = true);
            }
}

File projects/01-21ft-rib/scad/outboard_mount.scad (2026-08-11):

include <config.scad>
use <../../../shared/components/outboards/printables_1191848.scad>

// Mount 0 interface measured from the unmodified STL orthographic projection.
adapter_plate_size = mount0_adapter_plate_size;
adapter_edge_margin_y =
    (adapter_plate_size[1] - mount0_hole_spacing_y) / 2;
adapter_edge_margin_z =
    (adapter_plate_size[2] - mount0_hole_spacing_z) / 2;

assert(adapter_edge_margin_y >= 8,
    "Mount 0 adapter needs at least 8 mm side margin");
assert(adapter_edge_margin_z >= 8,
    "Mount 0 adapter needs at least 8 mm vertical margin");
assert(mount0_adapter_hole_diameter > mount0_vendor_hole_diameter,
    "Adapter holes must clear the vendor mount holes");

module mount0_hole_pattern(hole_diameter = mount0_adapter_hole_diameter,
        length = adapter_plate_size[0] + 2 * boolean_overlap) {
    for (y = [-mount0_hole_spacing_y / 2, mount0_hole_spacing_y / 2])
        for (z = [-mount0_hole_spacing_z / 2, mount0_hole_spacing_z / 2])
            translate([0, y, z])
                rotate([0, 90, 0])
                    cylinder(h = length, d = hole_diameter, center = true);
}

module rib_mount0_adapter_plate() {
    difference() {
        cube(adapter_plate_size, center = true);
        mount0_hole_pattern();
        rotate([0, 90, 0])
            cylinder(h = adapter_plate_size[0] + 2 * boolean_overlap,
                d = mount0_center_clearance_diameter, center = true);

    }
}


module rib_mount0_adapter_reference() {
    translate(mount0_adapter_center)
        rib_mount0_adapter_plate();
}

module mount0_vendor_reference() {
    rotate([0, 0, -90])
        outboard_1191848_mount_reference(0);
}

module mount0_interface_check(explode = 5) {
    color([0.95, 0.62, 0.12])
        mount0_vendor_reference();

    // Vendor mount spans about 17.63 mm along boat X after orientation.
    // Place the adapter on the transom side of its broad face.
    color([0.15, 0.45, 0.85, 0.65])
        translate([-(8.815 + adapter_plate_size[0] / 2 + explode), 0, 0])
            rib_mount0_adapter_plate();

    // Show the shared four-hole axes across both parts.
    color([0.9, 0.1, 0.2, 0.8])
        mount0_hole_pattern(
            hole_diameter = 1.2,
            length = 40 + explode
        );
}

// Compatibility aliases for the existing whole-boat fit preview.
module rib_outboard_adapter_envelope() {
    rib_mount0_adapter_reference();
}

module rib_outboard_reference(show_vendor = false) {
    translate(mount0_vendor_center)
        rotate([0, 0, -90])
            if (show_vendor)
                outboard_1191848_reference();
            else
                outboard_1191848_envelope();
}

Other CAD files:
projects/02-21ft-rib-trailer/3mf/bow_stop.3mf
projects/02-21ft-rib-trailer/3mf/plates/trailer_petg_plate_04.3mf
projects/02-21ft-rib-trailer/3mf/v_rail_joint_plate.3mf
projects/01-21ft-rib/stl/bow_rail_port.stl
projects/01-21ft-rib/scad/outboard_xl_adapter.scad
projects/01-21ft-rib/scad/aft_bench.scad
projects/01-21ft-rib/scad/assembly.scad
projects/01-21ft-rib/scad/assembly_with_motor.scad
projects/01-21ft-rib/scad/bow_bench.scad
projects/01-21ft-rib/scad/bow_eye.scad
projects/01-21ft-rib/scad/console.scad
projects/01-21ft-rib/scad/floor.scad
projects/01-21ft-rib/scad/helm_bench.scad
projects/01-21ft-rib/scad/hull.scad
projects/01-21ft-rib/scad/hull_geometry.scad
projects/01-21ft-rib/scad/ladder.scad
projects/01-21ft-rib/scad/stern.scad
projects/01-21ft-rib/src/hull_stage4.scad
projects/01-21ft-rib/src/stern_stage3.scad
projects/01-21ft-rib/stl/aft_bench_backrest.stl
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

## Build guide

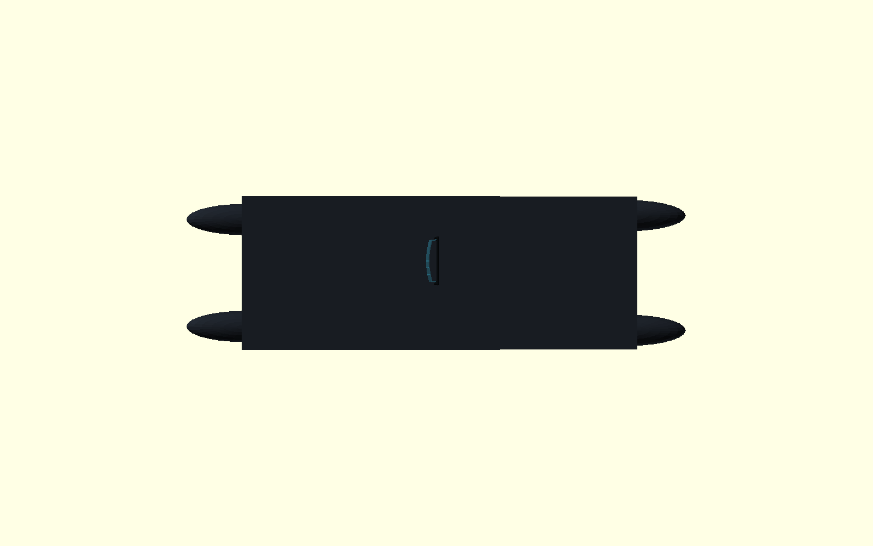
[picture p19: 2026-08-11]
projects/01-21ft-rib/png/assembly_top.png

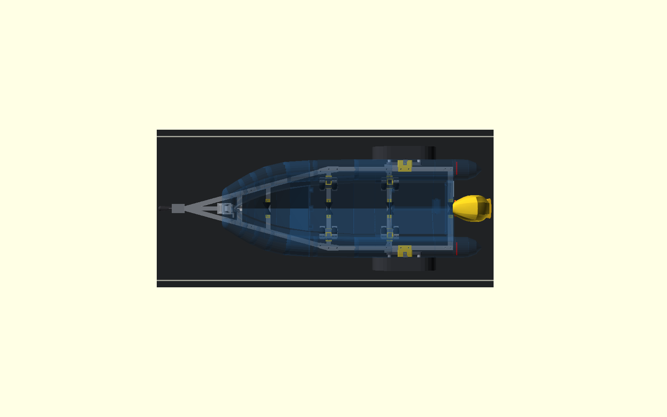
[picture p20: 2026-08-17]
projects/02-21ft-rib-trailer/png/assembly_top.png

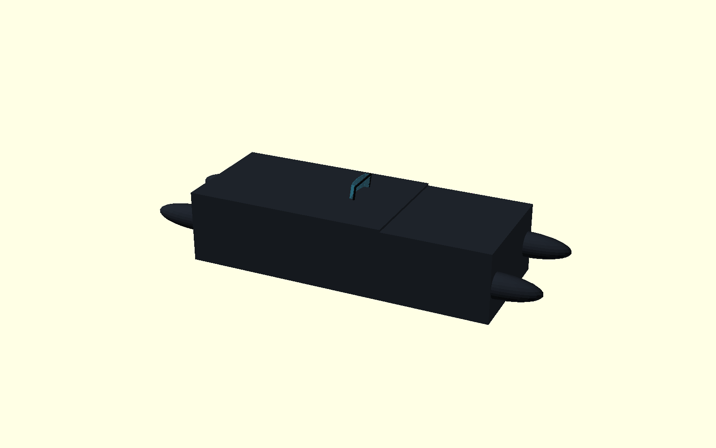
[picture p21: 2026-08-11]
projects/01-21ft-rib/png/assembly_isometric.png

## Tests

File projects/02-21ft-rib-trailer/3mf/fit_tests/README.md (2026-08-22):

# Skjøte- og koblingstest

Print og godkjenn denne pakken før `remaining_after_trial` brukes. Kupongene er fullskala utsnitt av produksjonsgeometrien; hull, anleggsflater og klaringer er identiske. Bruk faktiske M3-skruer, skiver og muttere under kontrollen.

Godkjenn: fri innføring uten tvang, ingen synlig vridning, gjennomgående hull som flukter, plater som ligger plant, og fri vipping i begge siderulleledd.

## Monteringskontroll

1. Monter `fit_v_front` mot `fit_v_rear` med to M3-bolter. Halvdelene skal gli helt sammen uten bøying eller filing.
2. Før tungen på `coupler_mount_adapter` inn i `fit_coupler_frame` og monter begge M3-boltene. Begge hull skal være helt gjennomgående.
3. Legg `fit_splice_front` og `fit_splice_rear` ende mot ende og monter `splice_plate` på utsiden.
4. Monter `fit_mid_rail` mot `fit_mid_crossmember` med én `crossmember_joint_plate_mid` over og én under. Platene skal ligge plant.
5. Gjenta med `fit_rear_rail`, `fit_rear_crossmember` og de to bakre skjøteplatene.
6. Monter `fit_side_post_head` mellom hovedørene på `side_double_roller_cradle`. Monter deretter `side_roller_wobble_holder` rundt én av de små knastene. Begge ledd skal vippe fritt uten merkbar slark eller gnissing.

Stopp videre produksjonsprint ved feil. Mål avviket med skyvelære og korriger den delte parameteren i `config.scad`; ikke fil til testdelen passer og deretter anta at produksjonsdelen er riktig.

## Plateinnhold

A1, 256 × 256 mm. Antallene dekker én komplett henger.
Prosjektfilene inneholder totalt 1 fysiske platefaner.

## fit_test_plate_01.3mf

Fysiske platefaner: 1

- `coupler_mount_adapter` × 1
- `crossmember_joint_plate_mid` × 2
- `crossmember_joint_plate_rear` × 2
- `fit_coupler_frame` × 1
- `fit_mid_crossmember` × 1
- `fit_mid_rail` × 1
- `fit_rear_crossmember` × 1
- `fit_rear_rail` × 1
- `fit_side_post_head` × 1
- `fit_splice_front` × 1
- `fit_splice_rear` × 1
- `fit_v_front` × 1
- `fit_v_rear` × 1
- `side_double_roller_cradle` × 1
- `side_roller_wobble_holder` × 1
- `splice_plate` × 1

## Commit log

2026-08-11 Add printable 21ft RIB OpenSCAD model
    [aft_bench_stage1.scad, aft_bench_stage1_preview.scad, aft_bench_stage1_structure_preview.scad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]
2026-08-11 Remove obsolete OpenSCAD development files
    [aft_bench.scad, aft_bench_stage1_preview.scad, aft_bench_stage1_structure_preview.scad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]
2026-08-11 Add distributable STL and PNG exports
    [aft_bench.scad, aft_bench_backrest.stl, aft_bench_cushion.stl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]
2026-08-11 Fix complete assembly preview
2026-08-15 Add printable 21ft RIB trailer project
    [assembly.scad, boat_reference.scad, bogie.scad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]
2026-08-15 Fix embedded meshes in trailer plate projects
    [trailer_petg_plate_01.3mf, trailer_petg_plate_02.3mf, trailer_petg_plate_03.3mf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]
2026-08-15 Arrange trailer plates with Bambu clearances
    [trailer_petg_plate_01.3mf, trailer_petg_plate_02.3mf, trailer_petg_plate_03.3mf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]
2026-08-17 Fix trailer joints and add remaining print plates
    [assembly.scad, bogie_arm.3mf, bogie_arm.stl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]
2026-08-22 Add trailer fit tests and Claude handoff
    [assembly.scad, bogie_mount.3mf, coupler_mount_adapter.3mf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]
